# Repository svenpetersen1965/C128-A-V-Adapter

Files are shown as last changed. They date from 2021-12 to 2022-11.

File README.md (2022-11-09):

# C128-A-V-Adapter
An A/V-adaptor board for the Commodore C128. This board is intended to connect to the Commodore C128 and use standard cables (audio, composite with RCA connector and/or s-video with a mini-DIN cable).

It also provides a 330Ohm resistor, which attenuates the s-video chroma line. This resistor can be bridged with a jumper.

Also an optional stereo output on pin 7 of the a/v jack (stereo sid, FPGA SID etc.) can be connected to the right audio channel. By default, this channel is also connected to the (mono) audio output.

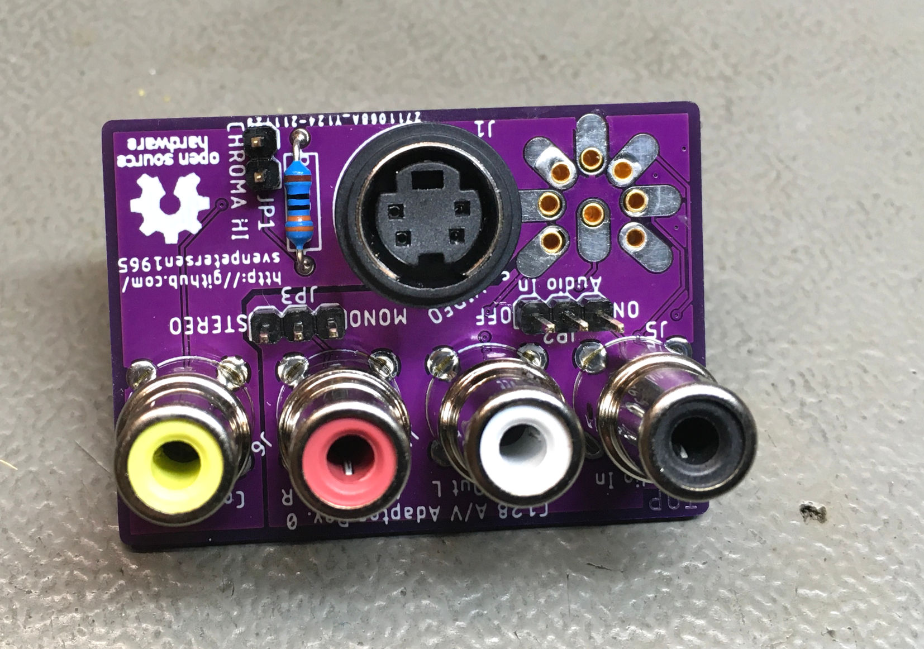
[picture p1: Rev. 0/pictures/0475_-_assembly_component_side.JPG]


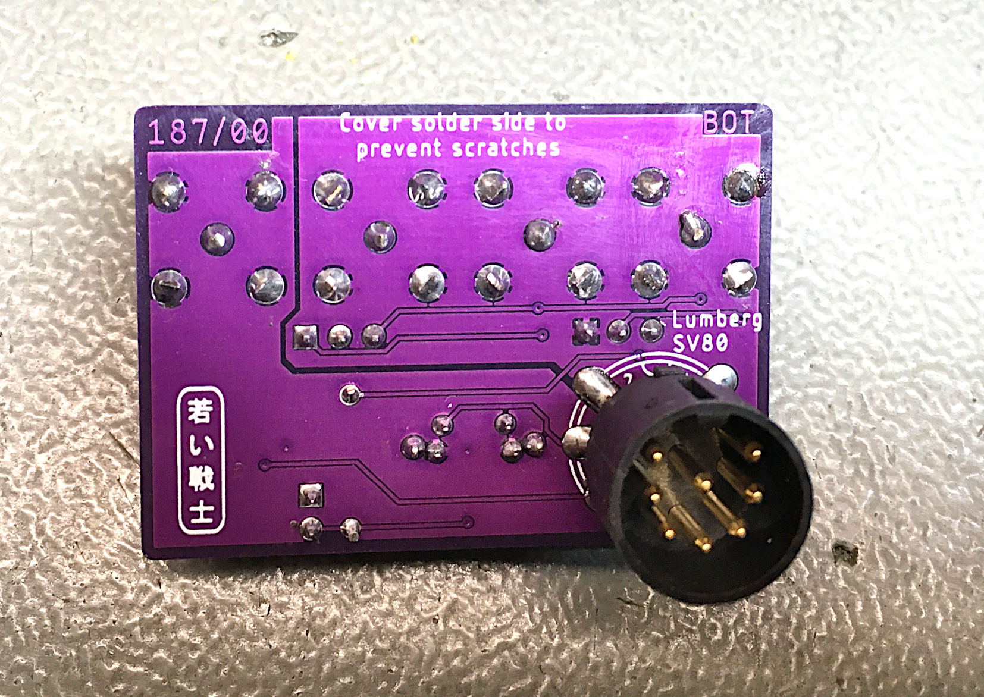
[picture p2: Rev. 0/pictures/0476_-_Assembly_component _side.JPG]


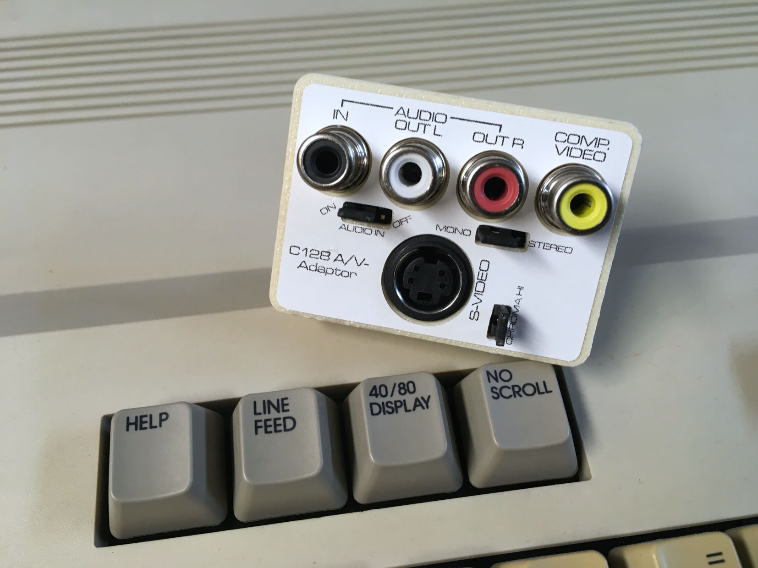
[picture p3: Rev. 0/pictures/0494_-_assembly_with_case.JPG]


# Rev. 1
This revision was required due to the obsolescence of the Lumberg BTOR1 RCA jacks. CUI Inc. RCJ-02* type conectors are used now. There are alternative RCA jacks from Keystone, which fit the same footprint (see BOM). Because of the new layout, a new case was required, too. There are recessions on the bottom shell for the solder pads, which have chancged in this board revision.

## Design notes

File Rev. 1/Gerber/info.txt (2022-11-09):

      
       Board: C128_AV-Adaptor
       Rev.:  1
  
       Files:
       ======
  
       All Gerber files are generated in extended gerber format (RS274X)
       *.TOP        : Film top copper
       *.BOT        :  -"- bottom copper
       *.STC        :  -"- top soldermask 
       *.STS        :  -"- bottom soldermask
       *.PLC        :  -"- silk screen top
       *.PLS        :  -"- silk screen bottom
       *.DK         : Drills plated Through (Excellon)
       *.NDK        : Drills not plated Through (Excellon)
       *.OUT        : Board outline

       Board Size:
       ===========
       Length     :   48.0 mm
       Width      :   34.0 mm
       Thickness  :   1.6 mm
       Material   :   FR 4
       Copper     :   35 um
       Surface    :   HASL
       
       Remarks:
       ========
       Width >= 8mil
       Distance >= 6mil
       Drill >= 0.6mm

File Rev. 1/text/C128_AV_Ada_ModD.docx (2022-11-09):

C128 A/V-Adaptor Rev. 1

Module Description

# Introduction

The A/V-Adaptor allows to connect standard S-Video and Audio or Composite-Video cables to the A/V-Jack of the Commodore C128.

A 330Ω resistor to attenuate the Chroma signal for S-Video is installed, but it can be deactivated by setting a jumper (JP2). This attenuation is required, since the chroma signal has a level, which is too high for standard S-Video. However, using the higher chroma signal can be desirable.

Further, the audio input can be connected to GND, in case it is not in use to reduce the noise introduction.

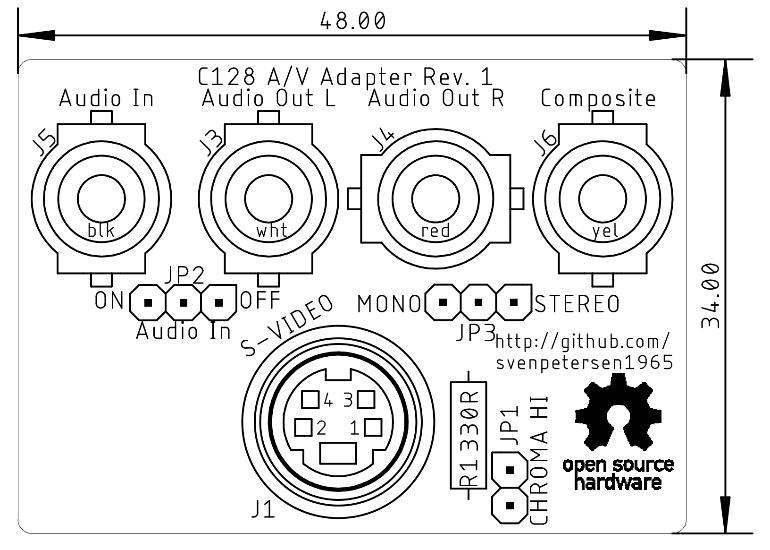
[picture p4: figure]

Figure 1: Component side of the A/V-Adaptor

The two audio output jacks can be connected by a jumper. Alternatively, the stereo sound output (A/V-Jack, pin 7, in case a 2nd SID is installed inside the C128) can be connected to the right channel of the audio output. The first SID output is connected to the left channel of the audio output.

# Connectors

## A/V-Plug – J2

The A/V-Plug for the C128 is the inner part of a Lumberg 033099 SV 80 DIN-Plug (8 pins, horse shoe = 262°). It provides a round plastic shell of the DIN-connector and long enough pins, so the adaptor can sit firmly in the A/V jack. The inner part of a cheaper (standard) connector cannot be used, since it does not sit firm enough.

Pin | Signal
1 | Luminance
2 | GND
3 | Audio Out (mono/left)
4 | Composite Video
5 | Audio In
6 | Chrominance
7 | Audio Out (right – if provided)
8 | -

## S-Video Jack – J1

A vertical PCB mount Mini-DIN jack (4 circuits)

Pin | Signal
1 | GND (Luminance)
2 | GND (Chrominance)
3 | Luminance
4 | Chrominance

## RCA-Jacks – J3, J4, J5 & J6

Connector | Signal
J3 | Audio Out (mono/left)
J4 | Audio Out (mono/right)
J5 | Audio In
J6 | Composite Video

# Jumpers

## Chrominance attenuation – JP1

The chrominance signal has a too high level for the standard S-Video chroma signal. The jumper bridges the 330Ω resistor (R1) to switch off this attenuation.

Status | Configuration
open | Attenuation active
Set | Attenuation inactive/off

## Audio Input Off – JP2

To reduce the noise introduction to the Audio Input, this can be grounded.

Status | Configuration
ON | SID Audio In connected to J5
OFF | SID Audio In connected to GND

## Mono/Stereo – JP3

The standard audio output of the SID is one channel (mono). In cases a 2nd SID is installed, the 2nd audio output is (usually) connected to Pin 7 of the Audio/Video jack of the C128. JP3 connected the right channel of the audio output (J4) to either J2, Pin 3 or Pin 7.

Status | Configuration
MONO | J4 connected to J2, Pin 3
STEREO | J4 connected to J2, Pin 7

# Assembly

Install the DIN plug (J2) on the solder side (bottom) first. Put the PCB on a suitable surface, the solder side up. Insert the DIN-plug, make sure, it is vertical and solder one pin first (from the solder side, which is pointing up, refer to Figure 2). Check again that the plug is straight, correct if required and finally solder all other pins.

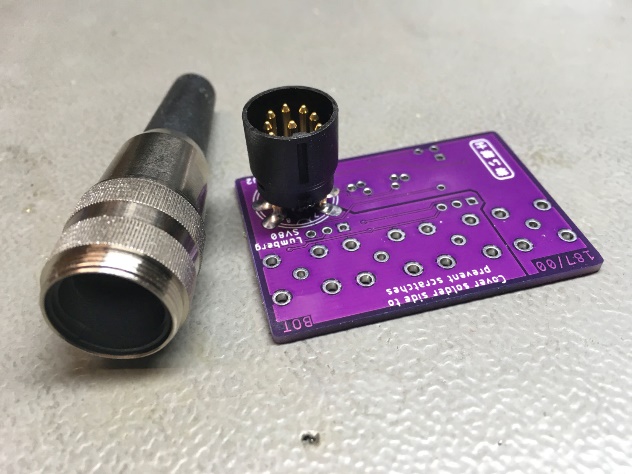
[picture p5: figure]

Figure 2: Soldering the DIN-plug J2 (PCB Rev. 0)

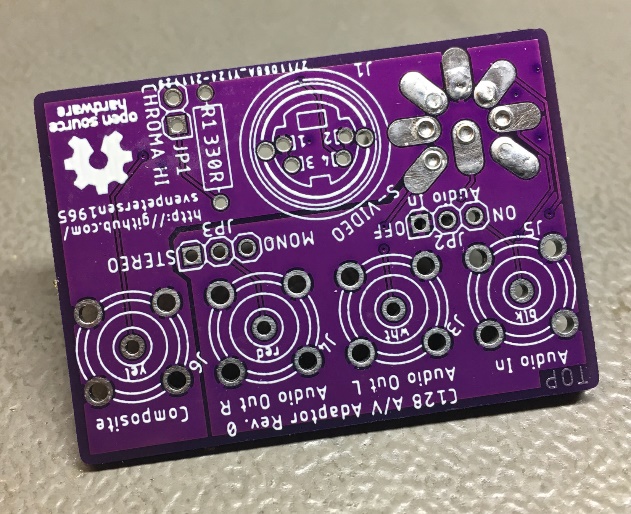
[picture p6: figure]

Figure 3: DIN-plug seen from the component side ("TOP") (PCB Rev. 0)

Install and solder all other components from the component side. Check the angle of the components, solder them from the solder side. Clip excess pin length.

In case no enclosure is used, cover the solder side (except J2) with duct tape to prevent scratching or install it in the provided 3D printed case.

# Revision History

## Rev. 0

- Fully functional prototype.

## Rev. 1

- The obsolete Lumberg BTOR1 RCA jacks were replaced by CUI Inc RCJ-02x type. There are alternative Keystone parts, that fit the same footprint (see BOM v1)
- A new 3D printed case is required.

C128_AV_Ada_ModD.docx 09.11.2022 10:47 Drafted by Sven Petersen Page 2 of 2 Doc.-No.: 187-6-01-01

C128_AV_Ada_ModD.docx 09.11.2022 10:47 Drafted by Sven Petersen Page 1 of 1 Doc.-No.: 000-6-00-00

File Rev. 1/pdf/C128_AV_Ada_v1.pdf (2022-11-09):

# Project Documentation

## C128 A/V-Adaptor

## Project number: 187

## Revision: 1

## Date: 28.08.2022

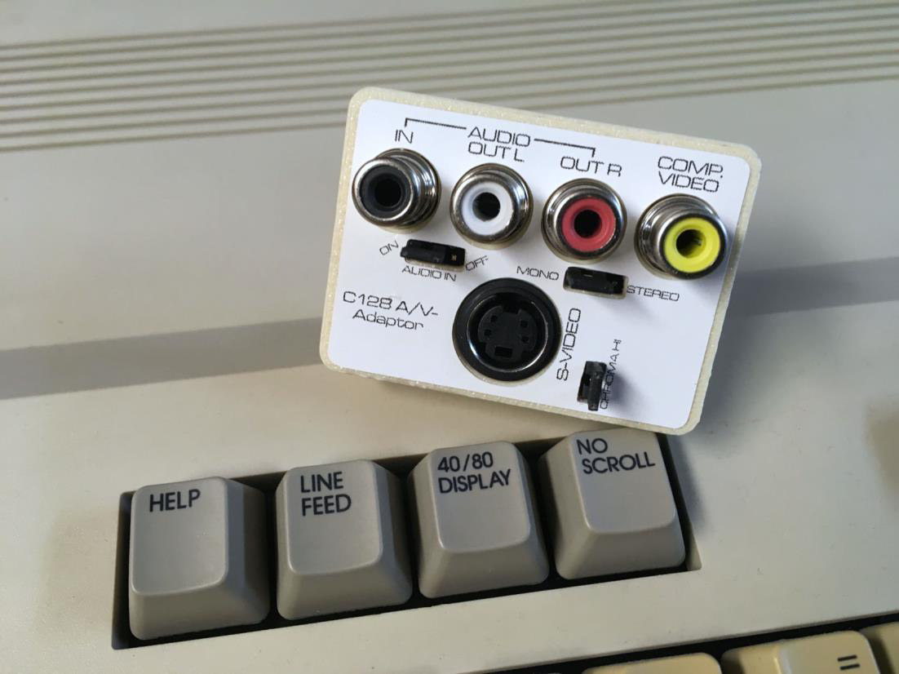
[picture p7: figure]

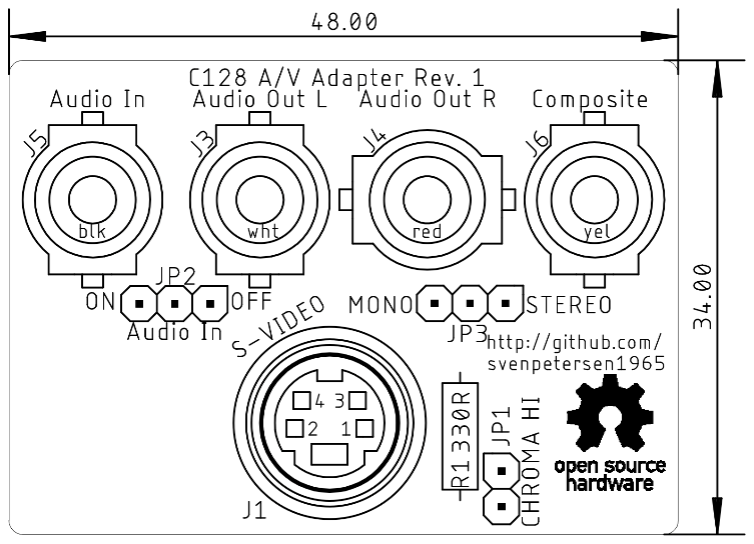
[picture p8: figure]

C128_AV_Ada_ModD.docx | | 09.11.2022 10:47
Drafted by Sven Petersen | Page 1 of 4 | Doc.-No.: 187-6-01-01

### C128 A/V-Adaptor Rev. 1

### Module Description

## Introduction

The A/V-Adaptor allows to connect standard S-Video and Audio or Composite-Video cables to the A/V-Jack of the Commodore C128.

A 330Ω resistor to attenuate the Chroma signal for S-Video is installed, but it can be deactivated by setting a jumper (JP2). This attenuation is required, since the chroma signal has a level, which is too high for standard S-Video. However, using the higher chroma signal can be desirable.

Further, the audio input can be connected to GND, in case it is not in use to reduce the noise introduction.

Figure 1: Component side of the A/V-Adaptor

The two audio output jacks can be connected by a jumper. Alternatively, the stereo sound output (A/V-Jack, pin 7, in case a 2nd SID is installed inside the C128) can be connected to the right channel of the audio output. The first SID output is connected to the left channel of the audio output.

## Connectors

### A/V-Plug – J2

The A/V-Plug for the C128 is the inner part of a Lumberg 033099 SV 80 DIN-Plug (8 pins, horse shoe = 262°). It provides a round plastic shell of the DIN-connector and long enough pins, so the adaptor can sit firmly in the A/V jack. The inner part of a cheaper (standard) connector cannot be used, since it does not sit firm enough.

C128_AV_Ada_ModD.docx | | 09.11.2022 10:47
Drafted by Sven Petersen | Page 2 of 4 | Doc.-No.: 187-6-01-01
Pin | Signal
1 Luminance
2 GND
3 Audio Out (mono/left)
4 Composite Video
5 Audio In
6 Chrominance
7 Audio Out (right – if provided) 8 -

### S-Video Jack – J1

A vertical PCB mount Mini-DIN jack (4 circuits)

Pin Signal
1 GND (Luminance)
2 GND (Chrominance)
3 Luminance
4 Chrominance

### RCA-Jacks – J3, J4, J5 & J6

Connector Signal
J3 | Audio Out (mono/left)
J4 | Audio Out (mono/right)
J5 | Audio In
J6 | Composite Video

## Jumpers

### Chrominance attenuation – JP1

The chrominance signal has a too high level for the standard S-Video chroma signal. The jumper bridges the 330Ω resistor (R1) to switch off this attenuation.

Status Configuration
open | Attenuation active
Set | Attenuation inactive/off

### Audio Input Off – JP2

To reduce the noise introduction to the Audio Input, this can be grounded.

Status Configuration
ON | SID Audio In connected to J5
OFF | SID Audio In connected to GND

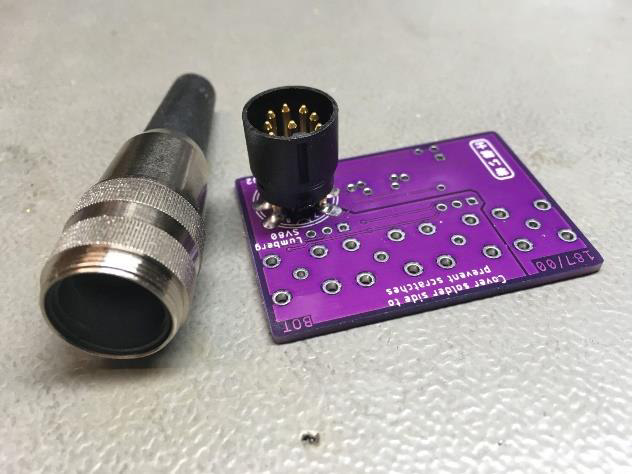
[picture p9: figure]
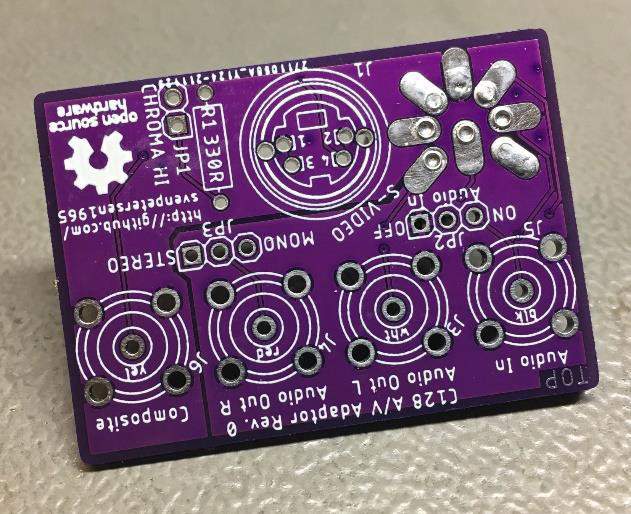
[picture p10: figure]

C128_AV_Ada_ModD.docx | | 09.11.2022 10:47
Drafted by Sven Petersen | Page 3 of 4 | Doc.-No.: 187-6-01-01

### Mono/Stereo – JP3

The standard audio output of the SID is one channel (mono). In cases a 2nd SID is installed, the 2nd audio output is (usually) connected to Pin 7 of the Audio/Video jack of the C128. JP3 connected the right channel of the audio output (J4) to either J2, Pin 3 or Pin 7.

Status | Configuration
MONO | J4 connected to J2, Pin 3
STEREO | J4 connected to J2, Pin 7

## Assembly

Install the DIN plug (J2) on the solder side (bottom) first. Put the PCB on a suitable surface, the solder side up. Insert the DIN-plug, make sure, it is vertical and solder one pin first (from the solder side, which is pointing up, refer to Figure 2). Check again that the plug is straight, correct if required and finally solder all other pins.

Figure 2: Soldering the DIN-plug J2 (PCB Rev. 0)

Figure 3: DIN-plug seen from the component side ("TOP") (PCB Rev. 0)

Install and solder all other components from the component side. Check the angle of the components, solder them from the solder side. Clip excess pin length.

In case no enclosure is used, cover the solder side (except J2) with duct tape to prevent scratching or install it in the provided 3D printed case.

C128_AV_Ada_ModD.docx | | 09.11.2022 10:47
Drafted by Sven Petersen | Page 4 of 4 | Doc.-No.: 187-6-01-01

## Revision History

### Rev. 0

- Fully functional prototype.

### Rev. 1

- The obsolete Lumberg BTOR1 RCA jacks were replaced by CUI Inc RCJ-02x type. There are alternative Keystone parts, that fit the same footprint (see BOM v1)
- A new 3D printed case is required.

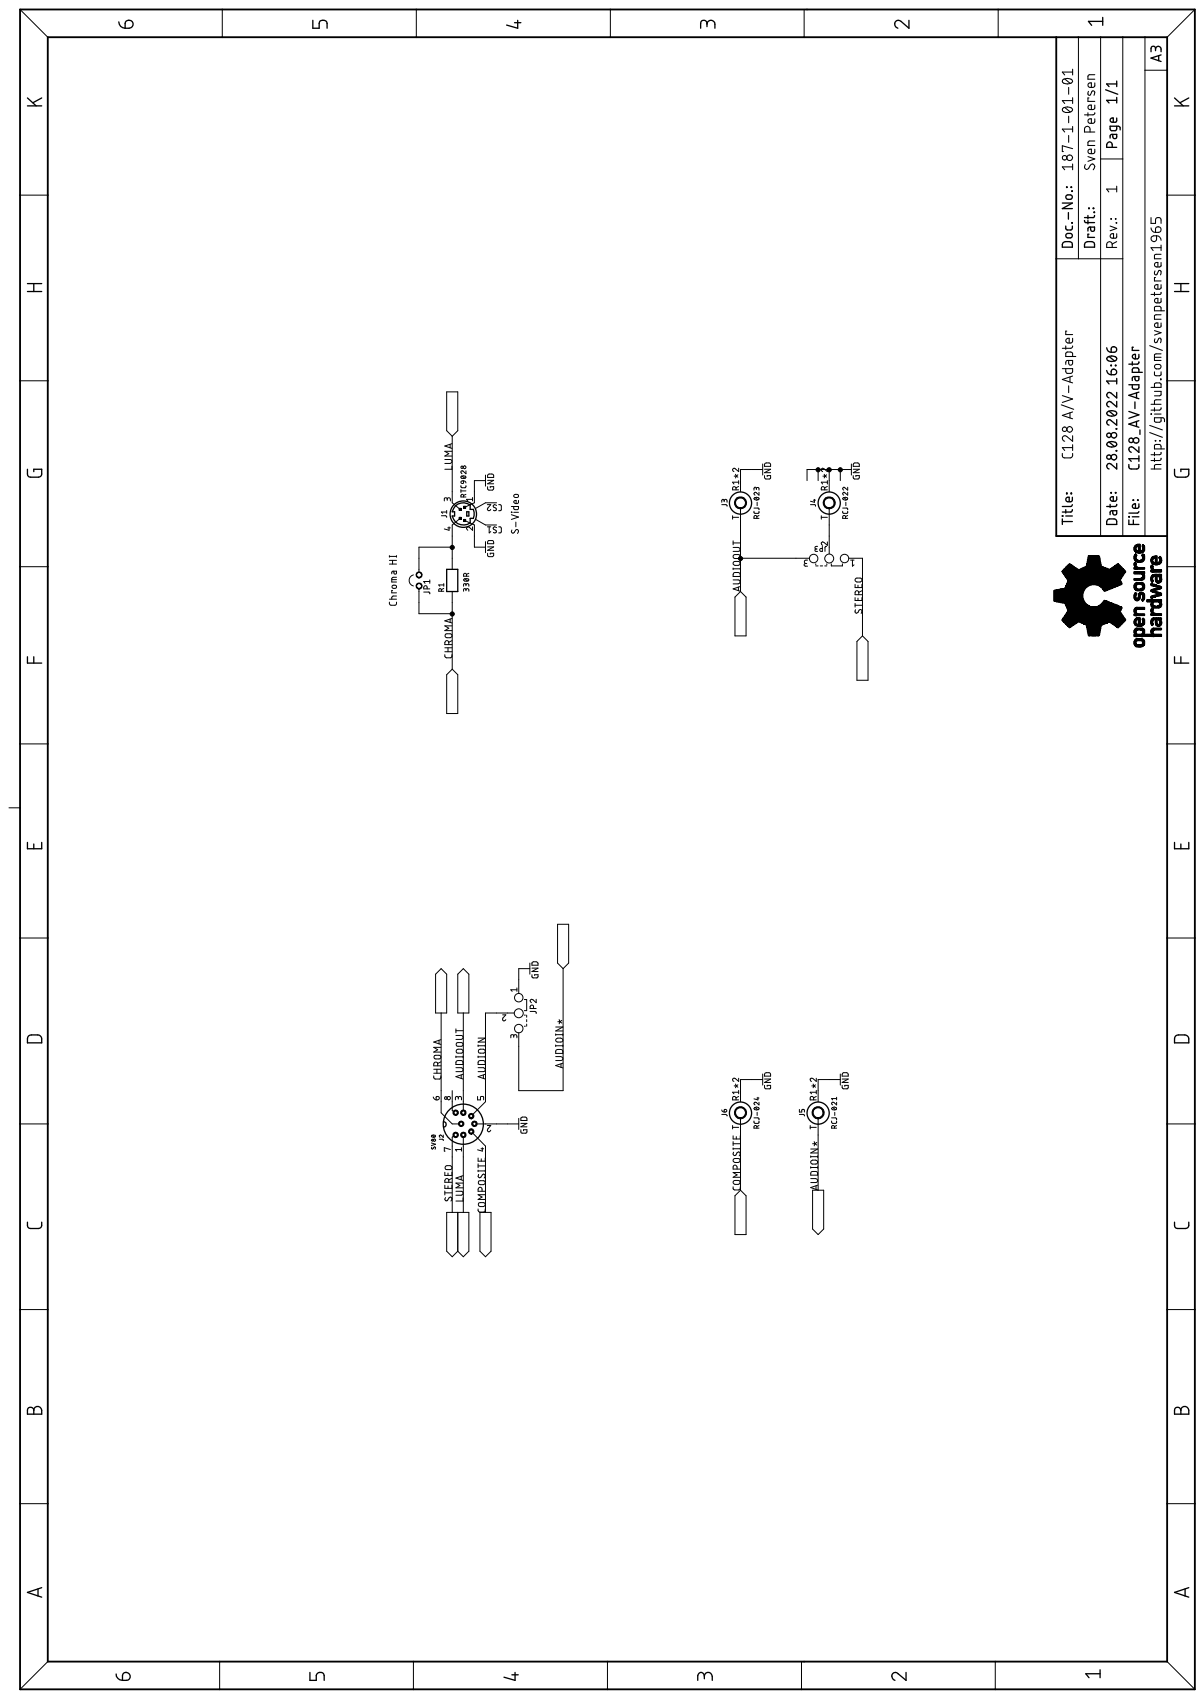
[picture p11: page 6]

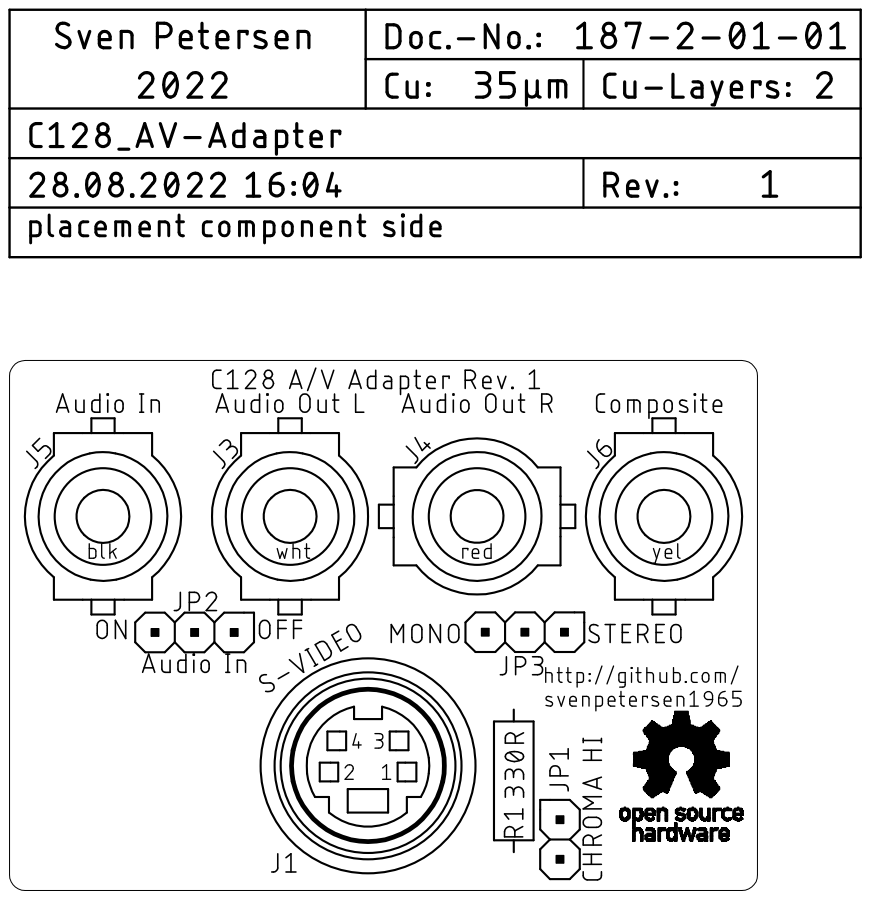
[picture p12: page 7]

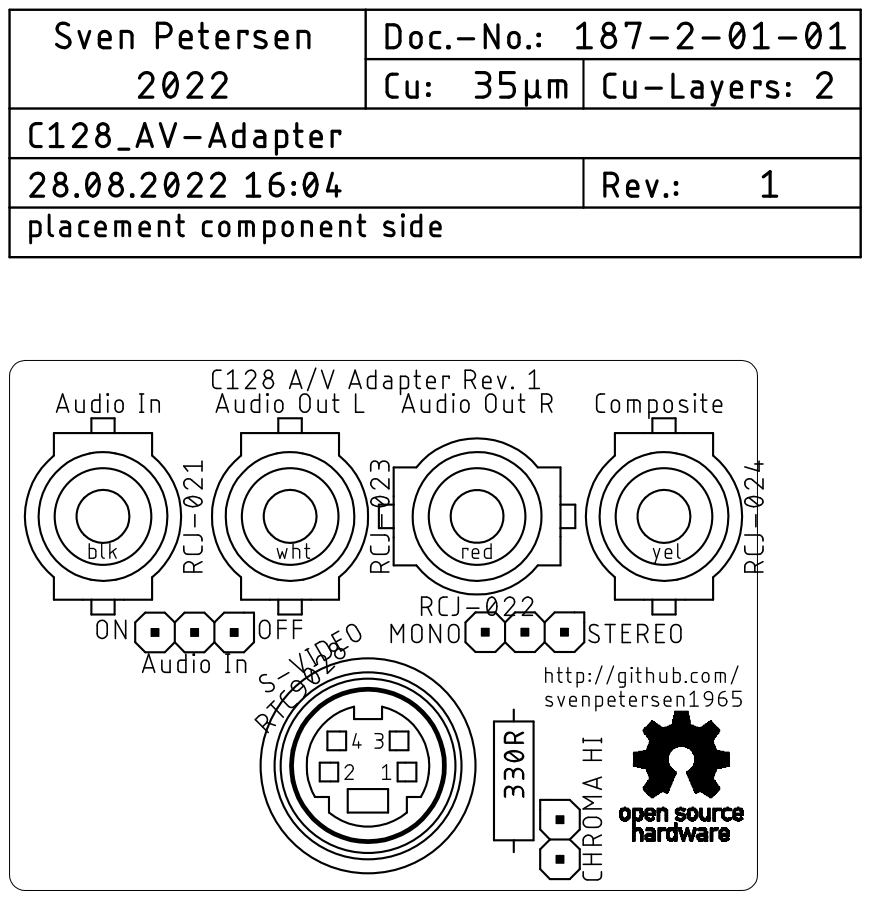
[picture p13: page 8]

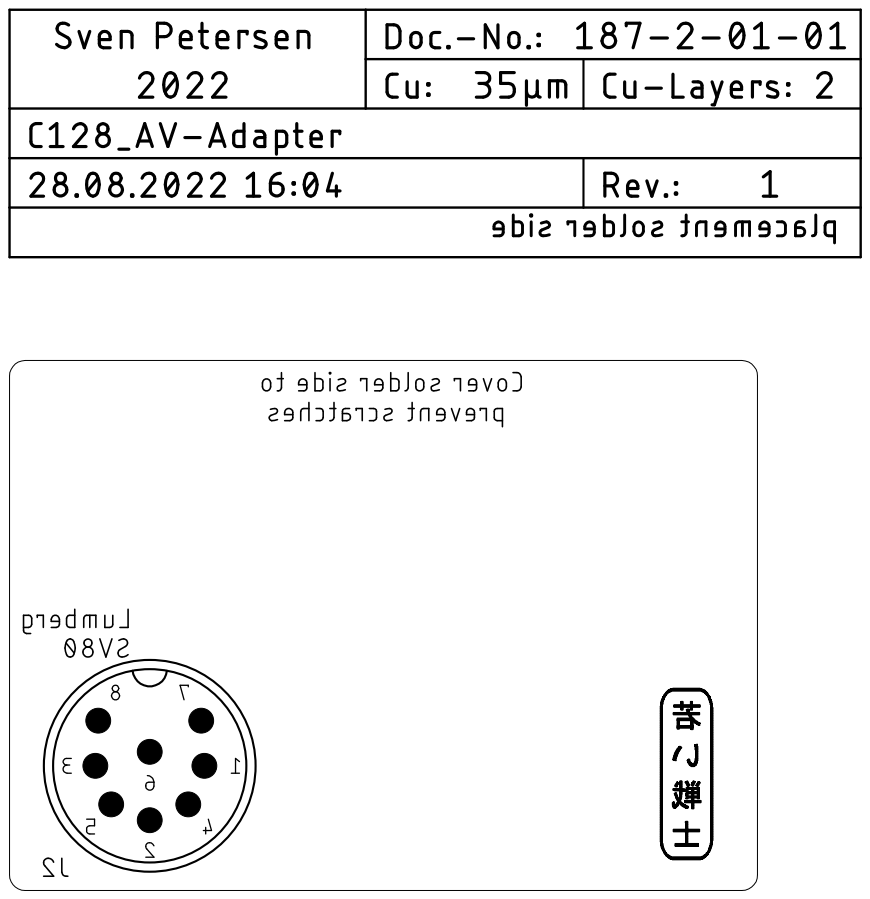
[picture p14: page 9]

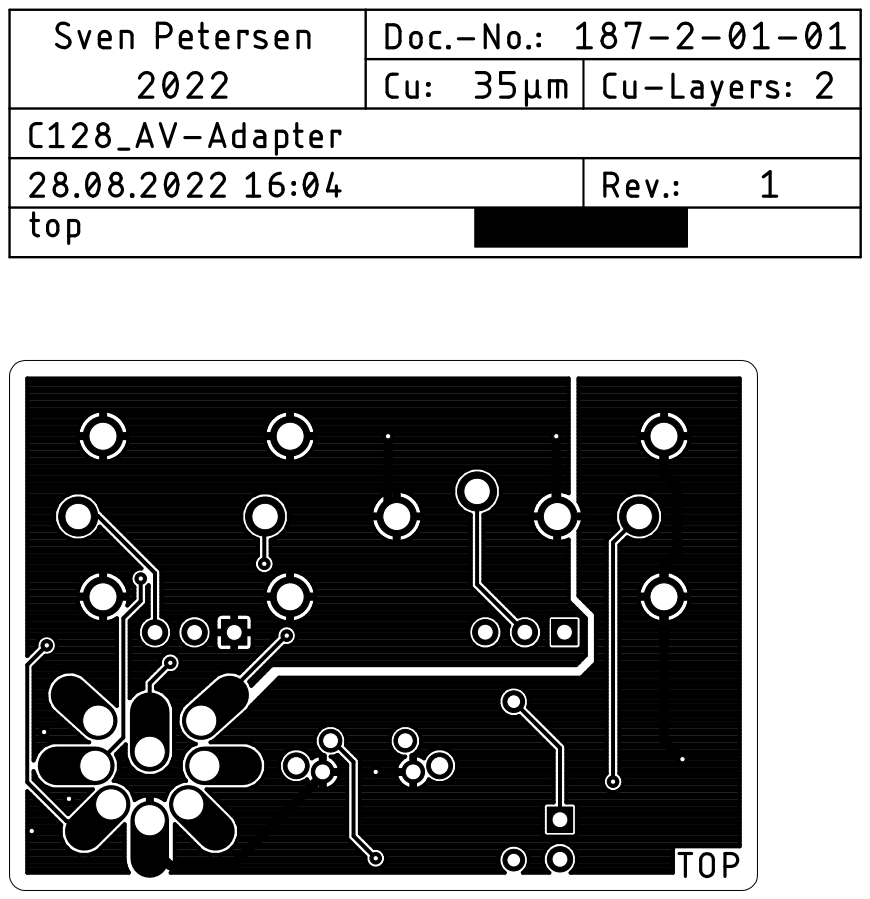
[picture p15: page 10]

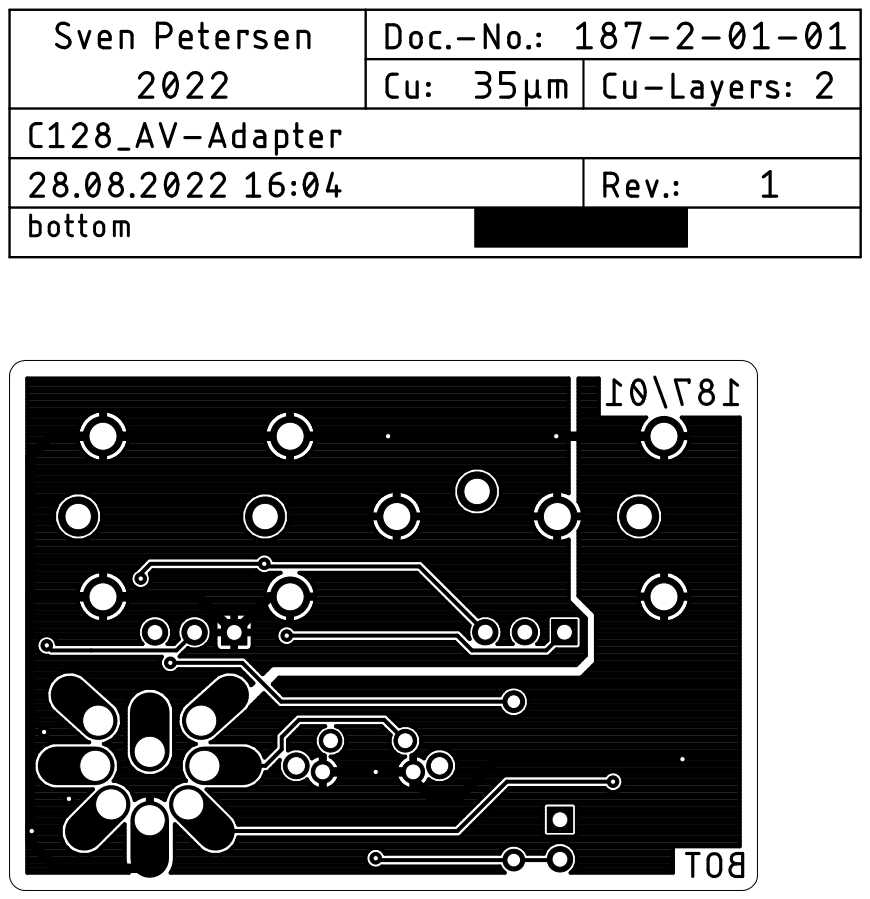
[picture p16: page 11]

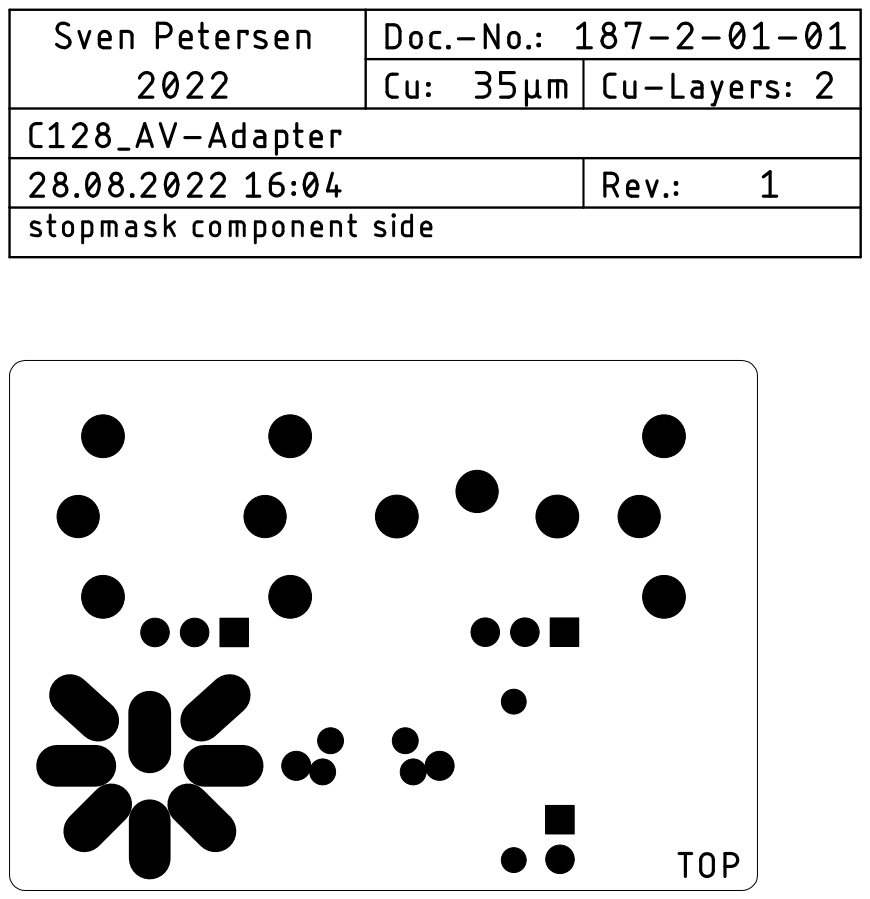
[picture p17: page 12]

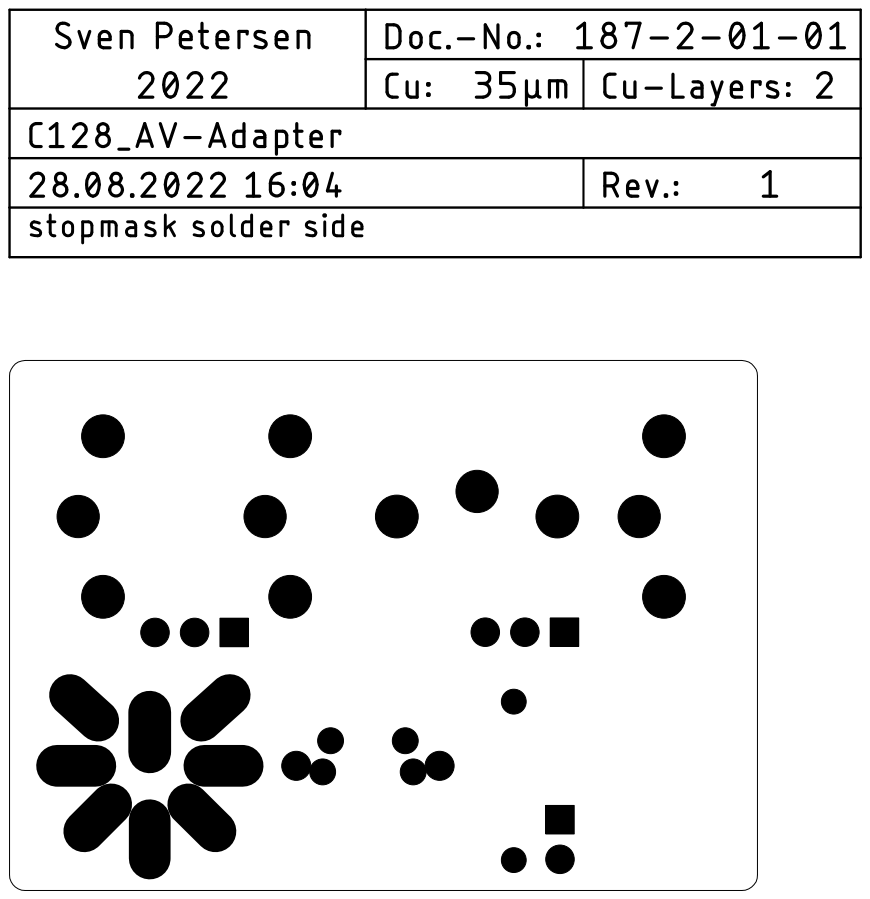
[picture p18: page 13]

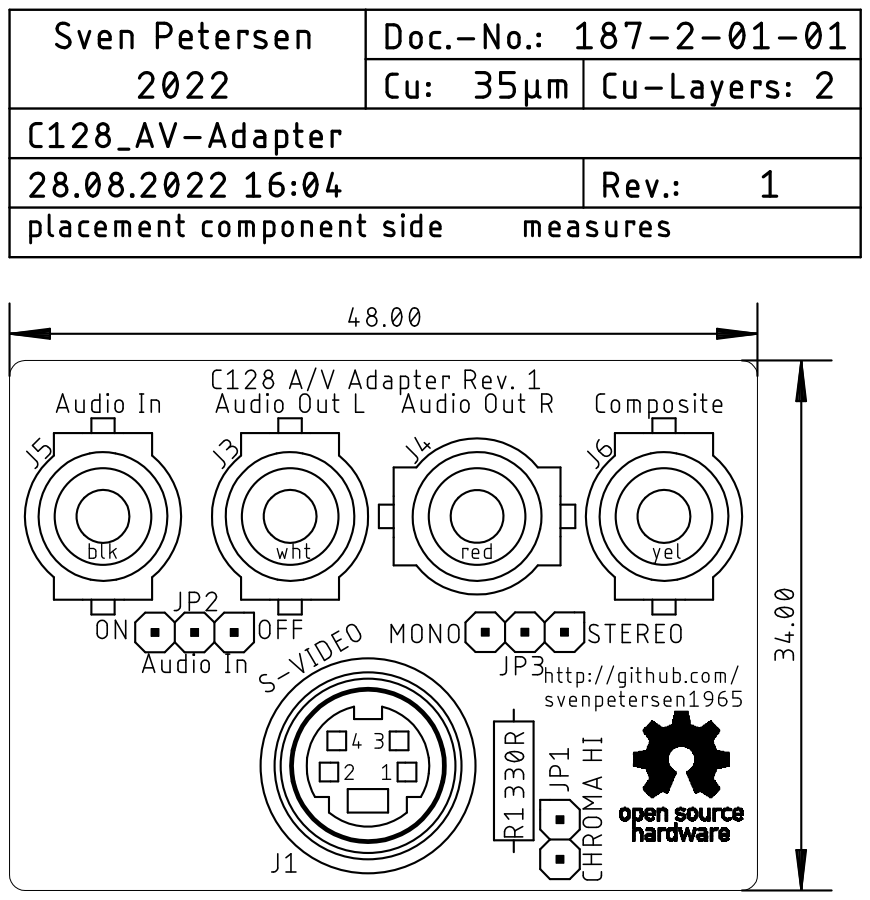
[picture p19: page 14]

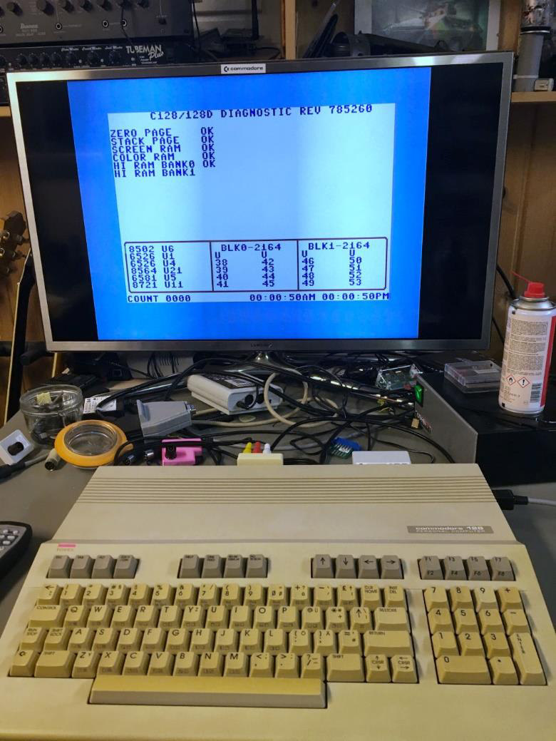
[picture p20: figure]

C128_AV_Ada_Test_1.docx | | 09.11.2022 17:33
Drafted by Sven Petersen | Page 1 of 4 | Doc.-No.: 187-6-02-01

### C128 A/V-Adaptor Rev. 1

### Testing v1.0

## Introduction

The test was conducted with a prototype of the A/V-Adaptor Rev. 1. For the electrical/functional tests a C128 was used. A Framemeister XRGB mini was used to connect an (HDMI) monitor.

Figure 1: Test Setup

## Tests

### Assembly

The prototype was assembled, all footprints worked out. The DIN plug was assembled the way described in the Module Description. No problems occurred while the assembly.

### Mechanical fitting

The A/V-Adaptor was installed on a C128, which works well with the prototype. It is required to install the DIN plug with a distance to the bottom side of the PCB to get deep enough into the video jack of the C128 to obtain a stabile seating.

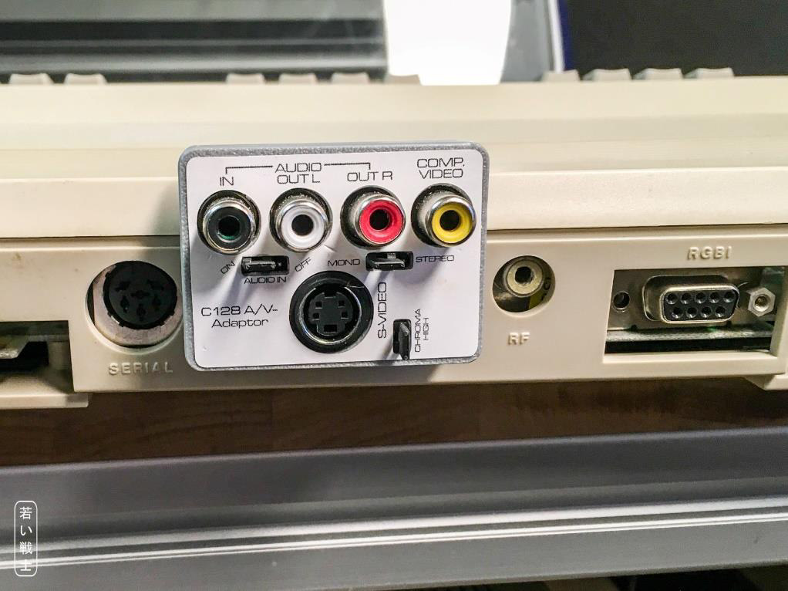
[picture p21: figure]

C128_AV_Ada_Test_1.docx | | 09.11.2022 17:33
Drafted by Sven Petersen | Page 2 of 4 | Doc.-No.: 187-6-02-01

Figure 2: Mechanical testing with a C128.

No ports are blocked.

### Functional testing

The A/V-adaptor was connected to the C128 and the computer was switched on. The jumpers were set to

Jumper | Setting
JP1 (Chroma Hi) | Close (=330R resistor bridged)
JP2 (Audio in) | Off (audio in → GND)
JP3 (mono/stereo) | Mono (both audio channels connected to J2, Pin 3)
Test | Result | Testing
S-Video cable connected | The displayed image was clear and not distorted | Ok
Audio cable | Both speakers had a clear audio output (mono) | Ok
Composite video | The displayed image was clear and not distorted | Ok
Audio input (JP2 → on) | The audio signal connected was passed through the filter. | Ok
Stereo mode | TBD | TBD
Chroma high (s-video), 330R resistor bridged | The quality of the displayed imaged changed. The colors got stronger and slightly distorted. This was expected. | Ok

The stereo mode was not tested.

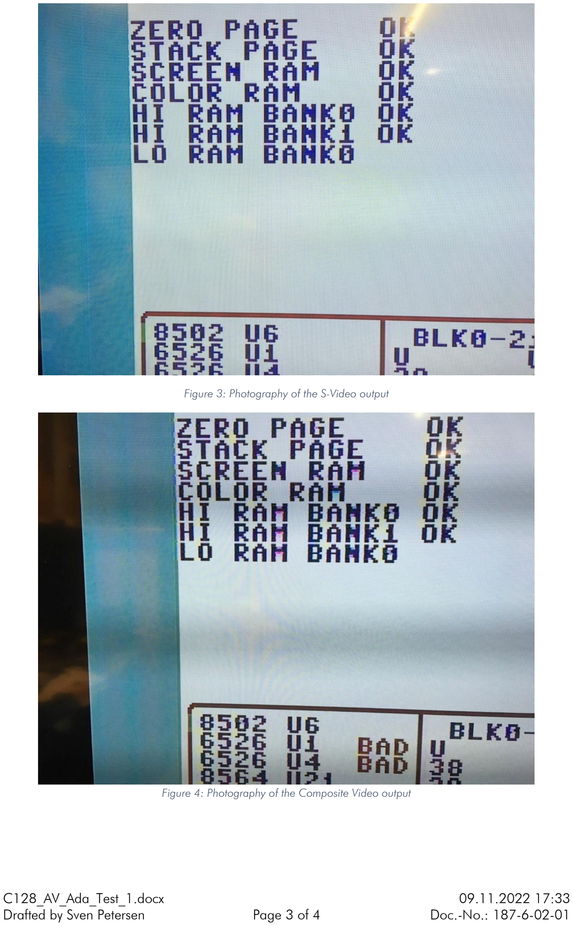
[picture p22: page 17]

C128_AV_Ada_Test_1.docx | | 09.11.2022 17:33
Drafted by Sven Petersen | Page 3 of 4 | Doc.-No.: 187-6-02-01

Figure 3: Photography of the S-Video output

Figure 4: Photography of the Composite Video output

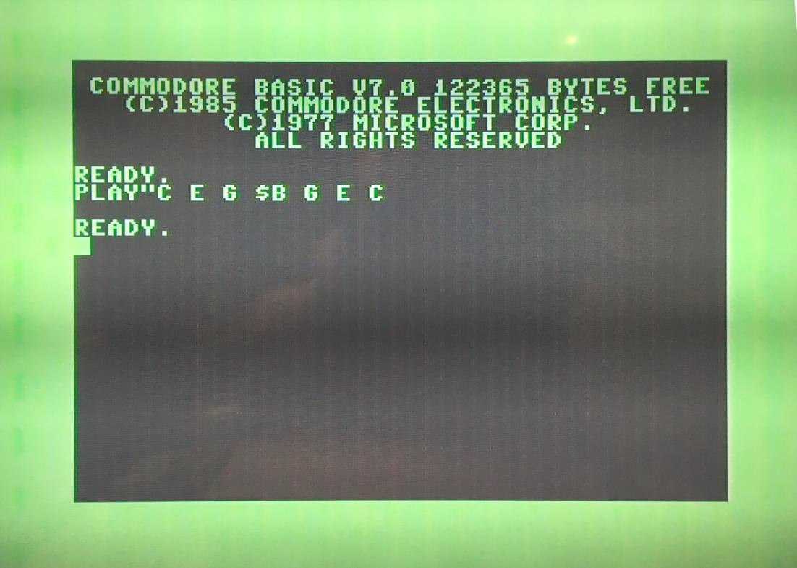
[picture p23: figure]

C128_AV_Ada_Test_1.docx | | 09.11.2022 17:33
Drafted by Sven Petersen | Page 4 of 4 | Doc.-No.: 187-6-02-01

Figure 5: Sound test

The sound test was accomplished by playing some notes from BASIC V7.0. These were audible.

NOTE: Photographing an TFT/LCD-Display never really shows the real image. That is matter due to raster effects (Moiré patterns) and dynamic effects (darker areas/strips).

### 3D-printed cases

After trimming the solder pins of the RCA jacks, all three versions of the board fit into the bottom shell. The respective top shells could be installed and fit well. The decals (labels) fit on the top shell.

The A/V-Adaptors passed a drop test (a drop of 1m on a table top).

## Test Result

The C128 A/V-Adaptor Rev. 1 is fully functional. It seems, that the colors of s-video and composite
video are looking more similar, when the jumper “Chroma High” is bridged.

Pos. Qty Value Footprint Ref.-No. Comment

1 1 187-2-01-01 2 Layer PCB Rev. 1 2 layer, Cu 35µ, HASL, 48.0mm x 34.0mm, 1.6mm FR4

2 2 1x 3p pin header, pitch

2.54mm

1X03 JP2, JP3 standard pin header, e.g. Reichelt RND 205-00624,

3 1 1x 2p pin header, pitch

2.54mm

1X02 JP1 standard pin header, e.g. Reichelt RND 205-00623

4 3 Jumper 2.54mm pitch jumper (JP1), (JP2), (JP3) Jumper (0,1") with holder/latch, e.g. tme.eu: JUMPER-H/B,
Farnell: 2396301, Newark: 93K5732 , Reichelt: JUMPER

2,54GL SW.

5 1 330R R-10 R1 resistor, 0.25W or more, 5% or better.

6 1 RCJ-021 RCJ-02X J5 CUI Inc., RCA jack, vertical, black. Mouser: 490-RCJ-021,
Digikey: CP-1406-ND. Alternative part: Keystone 585

7 1 RCJ-022 RCJ-02X J4 CUI Inc., RCA jack, vertical, red. Mouser: 490-RCJ-022,
Digikey: CP-1407-ND. Alternative part: Keystone 577

8 1 RCJ-023 RCJ-02X J3 CUI Inc., RCA jack, vertical, white. Mouser: 490-RCJ-023,
Digikey: CP-1408-ND. Alternative part: Keystone 584

9 1 RCJ-024 RCJ-02X J6 CUI Inc., RCA jack, vertical, yellow. Mouser: 490-RCJ-024,

Digikey: CP-1409-ND. Alternative part: Keystone 586

10 1 RTC9028 MINIDIN4_V J1 Mini-DIN, 4p, vertical. E.g. AliExpress:

RTConnector: RTC9028 (https://www.aliexpress.com/item/33032480787.html?spm=a2g0s.9042311.0.0.24354c4dZfdyek)

ebay.de (https://www.ebay.de/itm/5Stuck-Leiterplatten-Mount-4-Pin-Buchse-S-Jack-DVD-Mini-DIN-Sockel-Steckverbind/132869605733)

11 1 SV80 SV80_INNER J2 Inner part of Lumberg 033099 SV 80, e.G. Reichelt: LUM
SV 80, Newark: 23AH4043, Farnell: 1321482, TME.eu:
SV80, alliedelec.com: 70151558. LUM SV 50 for 5-pin

C64 and VIC-20

## C128 A/V-Adaptor Rev. 1

## Bill of Material Rev. 1.0

C128_AV_Adapt_BOM_v1_0.xlsx

Drafted by Sven Petersen Page 1 of 1

09.11.2022 17:36
Doc.No.: 187-5-01-01.0

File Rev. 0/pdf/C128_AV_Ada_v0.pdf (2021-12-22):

# Project Documentation

## C128 A/V-Adaptor

## Project number: 187

## Revision: 0

## Date: 22.12.2021


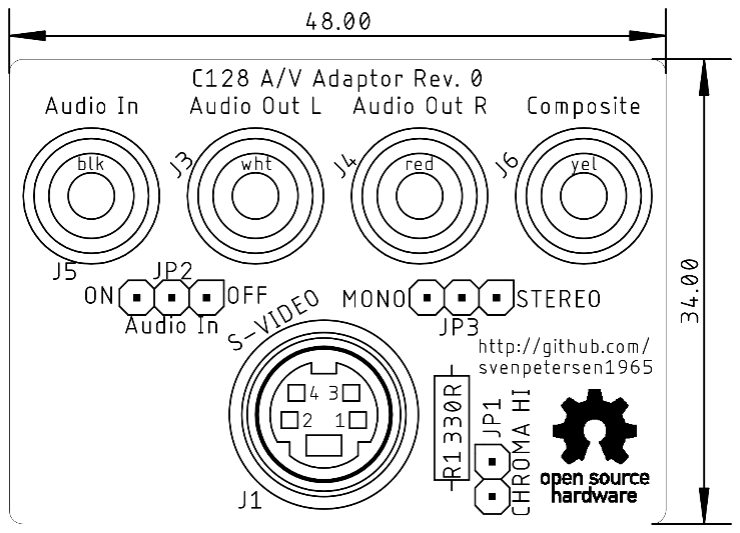
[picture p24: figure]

C128_AV_Ada_ModD.docx | | 22.12.2021 15:43
Drafted by Sven Petersen | Page 1 of 4 | Doc.-No.: 187-6-01-00

### C128 A/V-Adaptor Rev. 0

### Module Description

## Introduction

The A/V-Adaptor allows to connect standard S-Video and Audio or Composite-Video cables to the A/V-Jack of the Commodore C128.

A 330Ω resistor to attenuate the Chroma signal for S-Video is installed, but it can be deactivated by setting a jumper (JP2). This attenuation is required, since the chroma signal has a level, which is too high for standard S-Video. However, using the higher chroma signal can be desirable.

Further, the audio input can be connected to GND, in case it is not in use to reduce the noise introduction.

Figure 1: Component side of the A/V-Adaptor

The two audio output jacks can be connected by a jumper. Alternatively, the stereo sound output (A/V-Jack, pin 7, in case a 2nd SID is installed inside the C128) can be connected to the right channel of the audio output. The first SID output is connected to the left channel of the audio output.

## Connectors

### A/V-Plug – J2

The A/V-Plug for the C128 is the inner part of a Lumberg 033099 SV 80 DIN-Plug (8 pins, horse shoe = 262°). It provides a round plastic shell of the DIN-connector and long enough pins, so the adaptor can sit firmly in the A/V jack. The inner part of a cheaper (standard) connector cannot be used, since it does not sit firm enough.

C128_AV_Ada_ModD.docx | | 22.12.2021 15:43
Drafted by Sven Petersen | Page 2 of 4 | Doc.-No.: 187-6-01-00
Pin | Signal
1 Luminance
2 GND
3 Audio Out (mono/left)
4 Composite Video
5 Audio In
6 Chrominance
7 Audio Out (right – if provided) 8 -

### S-Video Jack – J1

A vertical PCB mount Mini-DIN jack (4 circuits)

Pin Signal
1 GND (Luminance)
2 GND (Chrominance)
3 Luminance
4 Chrominance

### RCA-Jacks – J3, J4, J5 & J6

Connector Signal
J3 | Audio Out (mono/left)
J4 | Audio Out (mono/right)
J5 | Audio In
J6 | Composite Video

## Jumpers

### Chrominance attenuation – JP1

The chrominance signal has a too high level for the standard S-Video chroma signal. The jumper bridges the 330Ω resistor (R1) to switch off this attenuation.

Status Configuration
open | Attenuation active
Set | Attenuation inactive/off

### Audio Input Off – JP2

To reduce the noise introduction to the Audio Input, this can be grounded.

Status Configuration
ON | SID Audio In connected to J5
OFF | SID Audio In connected to GND


C128_AV_Ada_ModD.docx | | 22.12.2021 15:43
Drafted by Sven Petersen | Page 3 of 4 | Doc.-No.: 187-6-01-00

### Mono/Stereo – JP3

The standard audio output of the SID is one channel (mono). In cases a 2nd SID is installed, the 2nd audio output is (usually) connected to Pin 7 of the Audio/Video jack of the C128. JP3 connected the right channel of the audio output (J4) to either J2, Pin 3 or Pin 7.

Status | Configuration
MONO | J4 connected to J2, Pin 3
STEREO | J4 connected to J2, Pin 7

## Assembly

Install the DIN plug (J2) on the solder side (bottom) first. Put the PCB on a suitable surface, the solder side up. Insert the DIN-plug, make sure, it is vertical and solder one pin first (from the solder side, which is pointing up, refer to Figure 2). Check again that the plug is straight, correct if required and finally solder all other pins.

Figure 2: Soldering the DIN-plug J2

Figure 3: DIN-plug seen from the component side ("TOP")

Install and solder all other components from the component side. Watch the angle of the components, solder them from the solder side. Clip excess pin length.

In case no enclosure is used, cover the solder side (except J2) with duct tape to prevent scratching or install it in the provided 3D printed case.

C128_AV_Ada_ModD.docx | | 22.12.2021 15:43
Drafted by Sven Petersen | Page 4 of 4 | Doc.-No.: 187-6-01-00

## Revision History

### Rev. 0

Fully functional prototype.

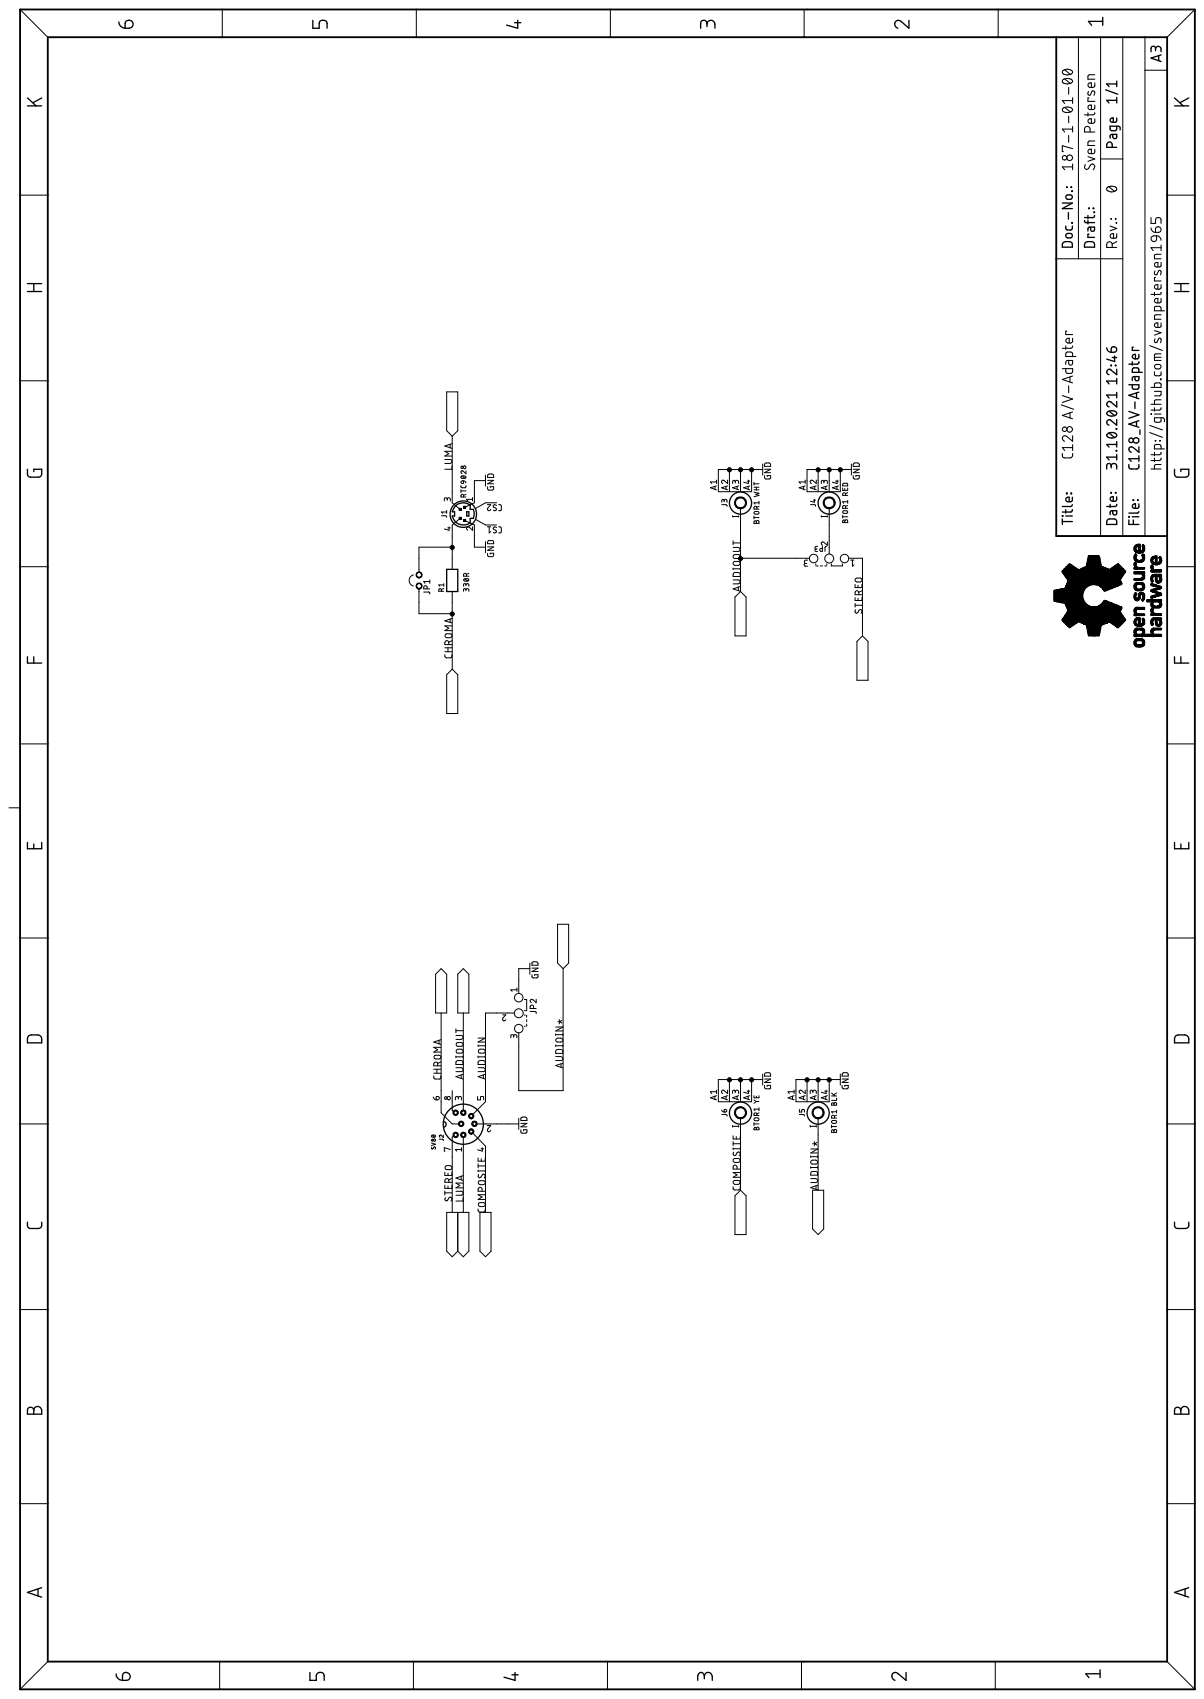
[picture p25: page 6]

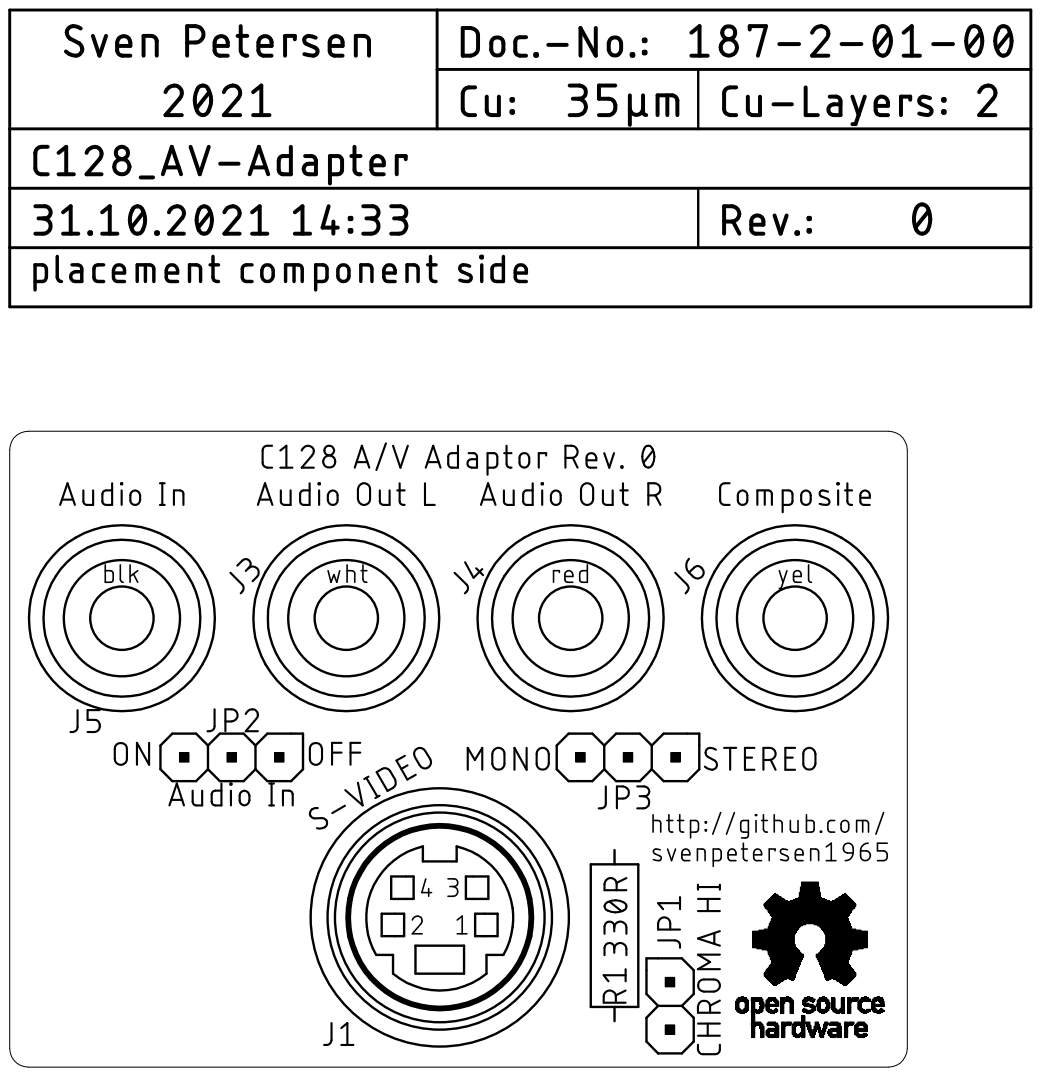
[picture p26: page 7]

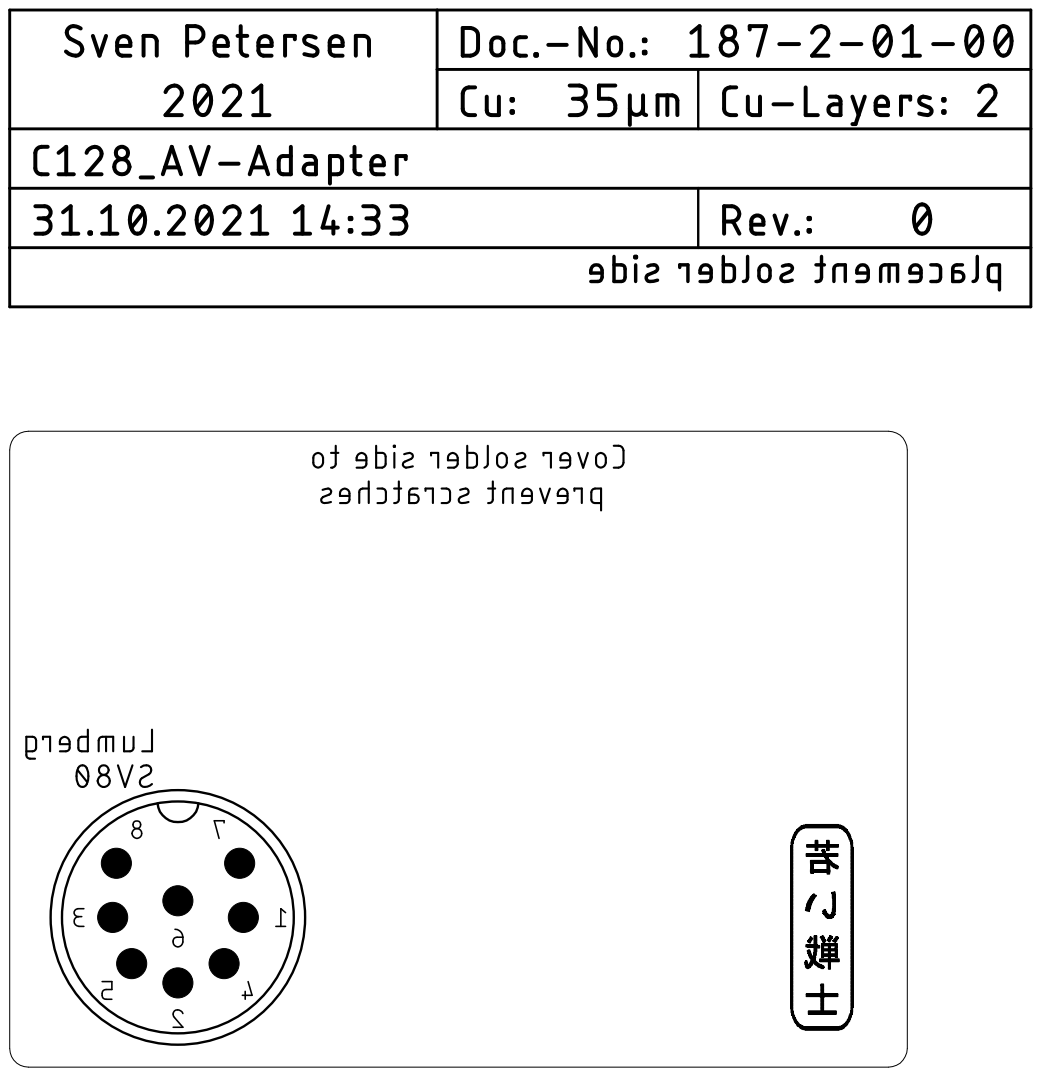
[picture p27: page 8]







C128_AV_Ada_Test_0.docx | | 22.12.2021 18:18
Drafted by Sven Petersen | Page 1 of 4 | Doc.-No.: 132-6-02-01

### C128 A/V-Adaptor Rev. 0

### Testing v0.0

## Introduction

The test was conducted with a prototype of the A/V-Adaptor Rev. 0. For the electrical/functional tests a C128 was used. A Framemeister XRGB mini was used to connect an (HDMI) monitor.

Figure 1: Test Setup

## Tests

### Assembly

The prototype was assembled, all footprints worked out. The DIN plug was assembled the way described in the Module Description. No problems occurred while the assembly.

### Mechanical fitting

The A/V-Adaptor was installed on a C128, which works well with the prototype. It is required to install the DIN plug with a distance to the bottom side of the PCB to get deep enough into the video jack of the C128 to obtain a stabile seating.


C128_AV_Ada_Test_0.docx | | 22.12.2021 18:18
Drafted by Sven Petersen | Page 2 of 4 | Doc.-No.: 132-6-02-01

Figure 2: Mechanical testing with a C128.

No ports are blocked.

### Functional testing

The A/V-adaptor was connected to the C128 and the computer was switched on. The jumpers were set to

Jumper | Setting
JP1 (Chroma Hi) | Close (=330R resistor bridged)
JP2 (Audio in) | Off (audio in → GND)
JP3 (mono/stereo) | Mono (both audio channels connected to J2, Pin 3)
Test | Result | Testing
S-Video cable connected | The displayed image was clear and not distorted | Ok
Audio cable | Both speakers had a clear audio output (mono) | Ok
Composite video | The displayed image was clear and not distorted | Ok
Audio input (JP2 → on) | The audio signal connected was passed through the filter. | Ok
Stereo mode | TBD | TBD
Chroma high (s-video), 330R resistor bridged | The quality of the displayed imaged changed. The colors got stronger and slightly distorted. This was expected. | Ok

The stereo mode was not tested.


C128_AV_Ada_Test_0.docx | | 22.12.2021 18:18
Drafted by Sven Petersen | Page 3 of 4 | Doc.-No.: 132-6-02-01

Figure 3: Photography of the S-Video output

Figure 4: Photography of the Composite Video output


C128_AV_Ada_Test_0.docx | | 22.12.2021 18:18
Drafted by Sven Petersen | Page 4 of 4 | Doc.-No.: 132-6-02-01

Figure 5: Sound test

The sound test was accomplished by playing some notes from BASIC V7.0. These were audible.

NOTE: Photographing an TFT/LCD-Display never really shows the real image. That is matter due to raster effects (Moiré patterns) and dynamic effects (darker areas/strips).

### 3D-printed cases

After trimming the solder pins of the RCA jacks, all three versions of the board fit into the bottom shell. The respective top shells could be installed and fit well. The decals (labels) fit on the top shell.

The A/V-Adaptors passed a drop test (a drop of 1m on a table top).

## Test Result

The C128 A/V-Adaptor Rev. 0 is fully functional. It seems, that the colors of s-video and composite video are looking more similar, when the jumper “Chroma High” is bridged.

Pos. Qty Value Footprint Ref.-No. Comment

1 1 187-2-01-00 2 Layer PCB Rev. 0 2 layer, Cu 35µ, HASL, 48.0mm x 34.0mm, 1.6mm FR4

2 2 1x 3p pin header, pitch

2.54mm

1X03 JP2, JP3 standard pin header, e.g. Reichelt RND 205-00624,

3 1 1x 2p pin header, pitch

2.54mm

1X02 JP1 standard pin header, e.g. Reichelt RND 205-00623

4 3 Jumper 2.54mm pitch jumper (JP1), (JP2), (JP3) Jumper (0,1") with holder/latch, e.g. tme.eu: JUMPER-H/B,
Farnell: 2396301, Newark: 93K5732 , Reichelt: JUMPER

2,54GL SW.

5 1 330R R-10 R1 resistor, 0.25W or more, 5% or better.

6 1 BTOR1 (black) BTOR1 J5 Lumberg, RCA jack, vertical, black. E.G. Reichelt LUM
BTOR1 SW, Farnell: 1217030, Newark: 96K7172,

TME.eu: BTOR1B

7 1 BTOR1 RED BTOR1 J4 Lumberg, RCA jack, vertical, red. E.G. Reichelt LUM BTOR1

RT, Farnell: 1368644, Newark: 53M6863, TME.eu:

BTOR1R

8 1 BTOR1 WHITE BTOR1 J3 Lumberg, RCA jack, vertical, white. E.G. Reichelt LUM
BTOR1 WS, Farnell: 1368645, Newark: 53M6864,

TME.eu: BTOR1W

9 1 BTOR1 YELLOW BTOR1 J6 Lumberg, RCA jack, vertical, yellow. E.G. Reichelt LUM
BTOR1 GE, Farnell: 1368642, Newark: 53M6865,

TME.eu: BTOR1Y

10 1 RTC9028 MINIDIN4_V J1 Mini-DIN, 4p, vertical. E.g. AliExpress:

RTConnector: RTC9028 (https://www.aliexpress.com/item/33032480787.html?spm=a2g0s.9042311.0.0.24354c4dZfdyek)

ebay.de (https://www.ebay.de/itm/5Stuck-Leiterplatten-Mount-4-Pin-Buchse-S-Jack-DVD-Mini-DIN-Sockel-Steckverbind/132869605733)

11 1 SV80 SV80_INNER J2 Inner part of Lumberg 033099 SV 80, e.G. Reichelt: LUM
SV 80, Newark: 23AH4043, Farnell: 1321482, TME.eu:
SV80, alliedelec.com: 70151558. LUM SV 50 for 5-pin

C64 and VIC-20

## C128 A/V-Adaptor Rev. 0

## Bill of Material Rev. 0.0

C128_AV_Adapt_BOM_v0_0.xlsx

Drafted by Sven Petersen Page 1 of 2

22.12.2021 18:18
Doc.No.: 187-5-01-00.0

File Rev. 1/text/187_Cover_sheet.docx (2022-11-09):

Project Documentation

C128 A/V-Adaptor

Project number: 187

Revision: 1

Date: 28.08.2022


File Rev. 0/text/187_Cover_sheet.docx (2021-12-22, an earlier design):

Project Documentation

C128 A/V-Adaptor

Project number: 187

Revision: 0

Date: 22.12.2021


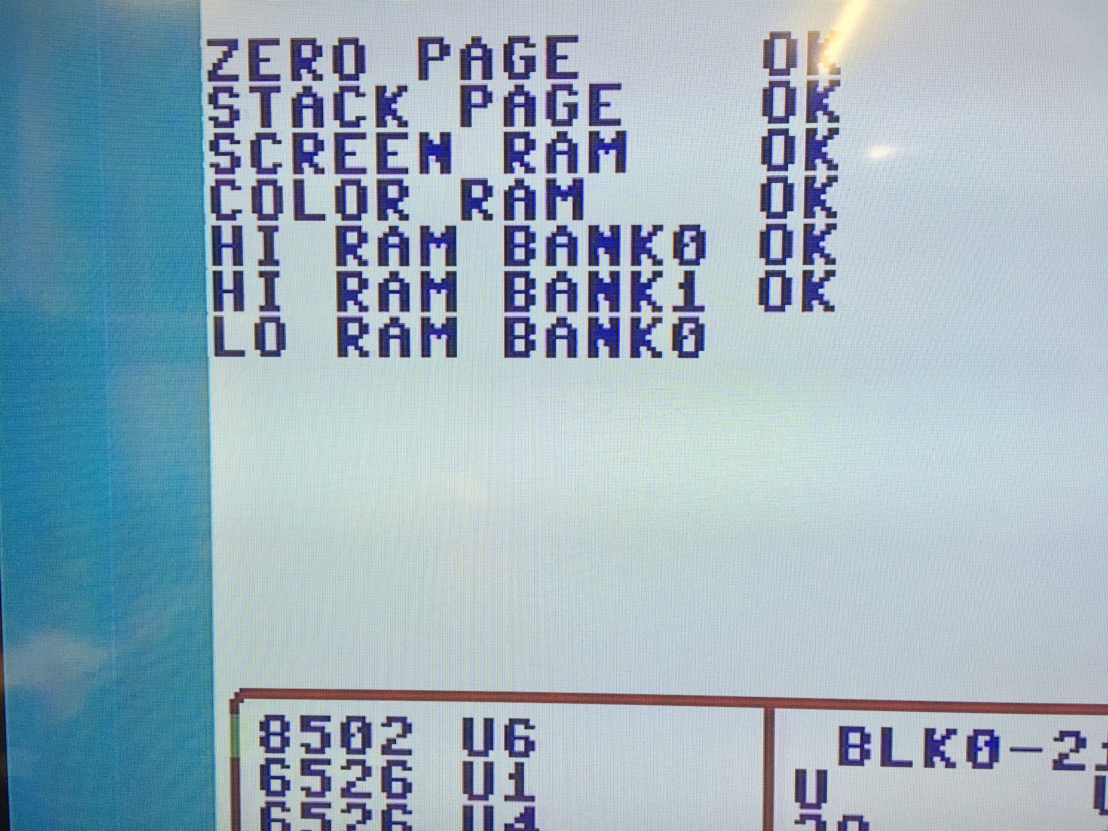
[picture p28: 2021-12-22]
Rev. 1/pictures/0481_-_s-video.JPG

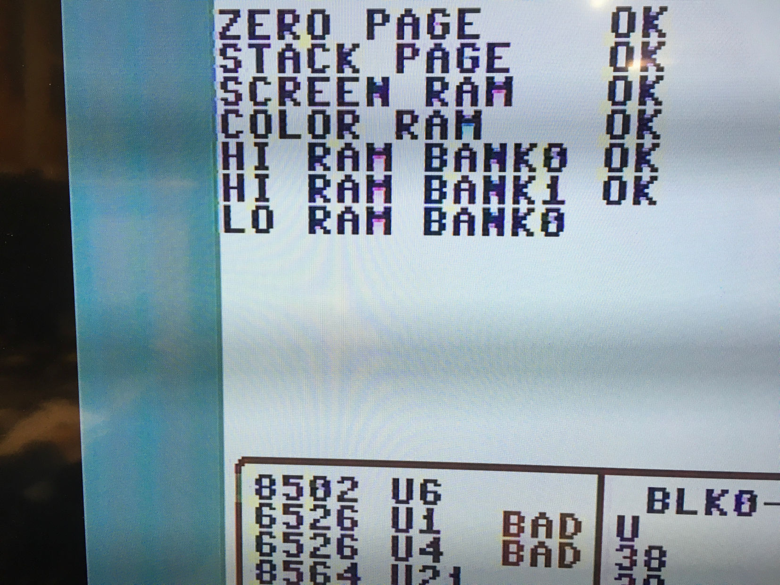
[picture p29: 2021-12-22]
Rev. 1/pictures/0482_-_composite.JPG

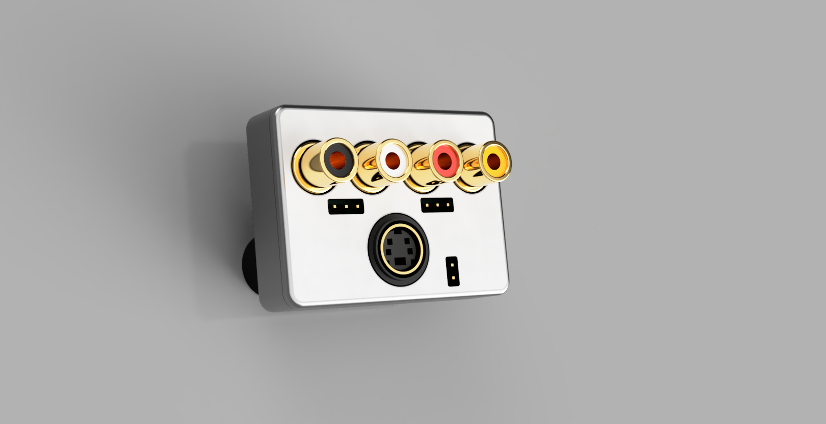
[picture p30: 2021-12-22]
Rev. 1/pictures/Rendered_image.PNG

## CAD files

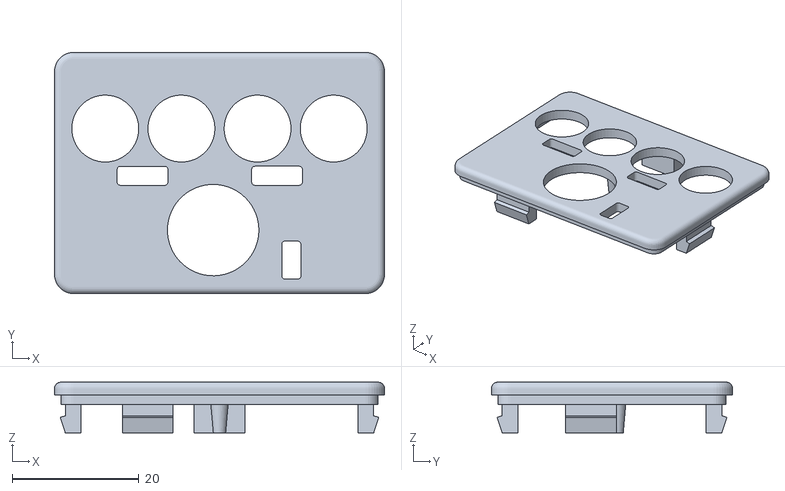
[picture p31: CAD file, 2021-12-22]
3D-printed case/Rev. 0/stl/C128_AVada_top.stl
52.0 x 38.0 x 8.00

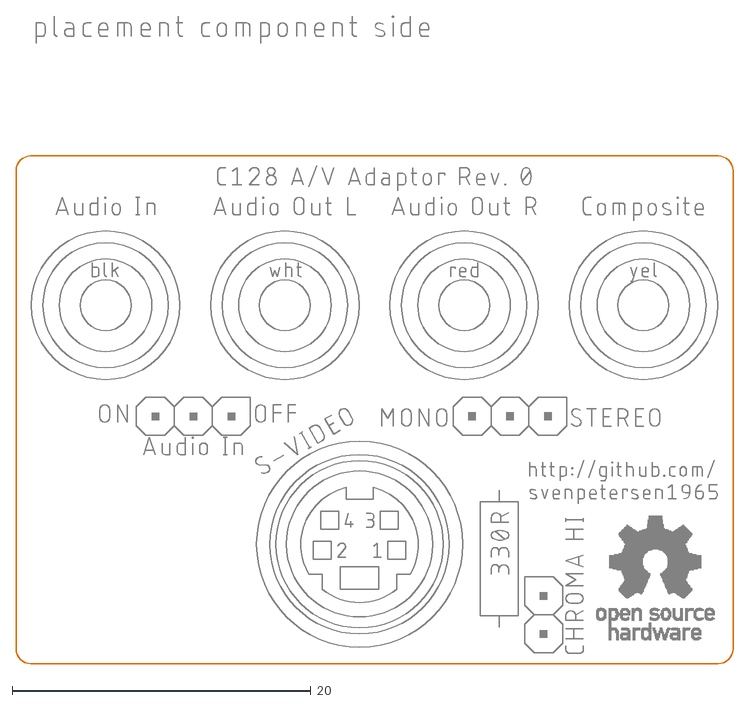
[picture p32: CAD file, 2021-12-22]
Rev. 0/dxf/C128_AV-Adapter_top.dxf
48.0 x 43.3

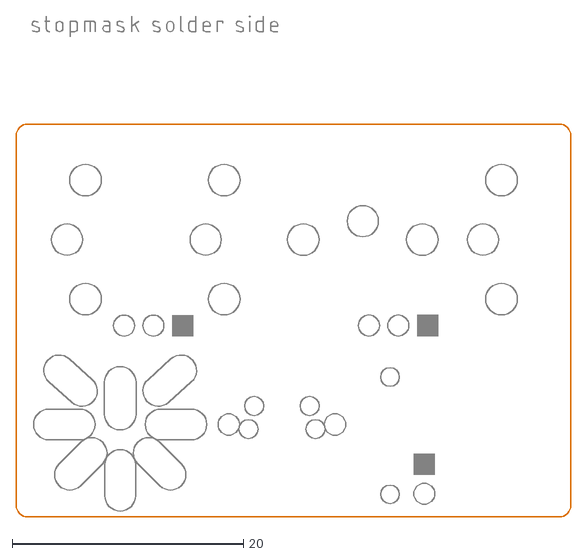
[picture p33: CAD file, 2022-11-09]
Rev. 1/dxf/C128_AV-Adapter_solderPads.dxf
48.0 x 43.3

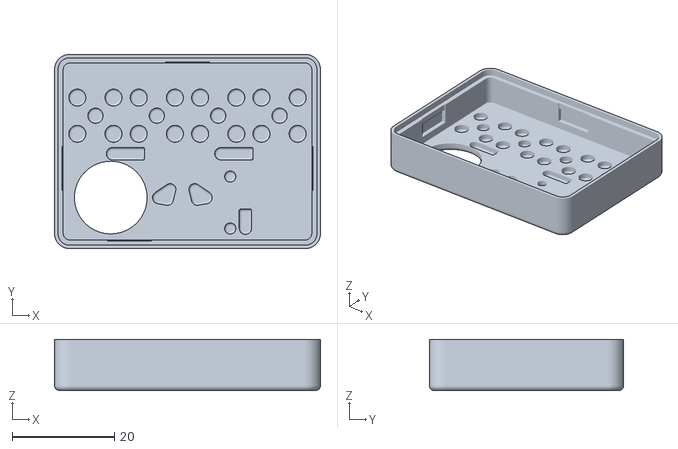
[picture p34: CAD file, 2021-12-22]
3D-printed case/Rev. 0/stl/C128_AVada_bottom.stl
52.0 x 38.0 x 10.0

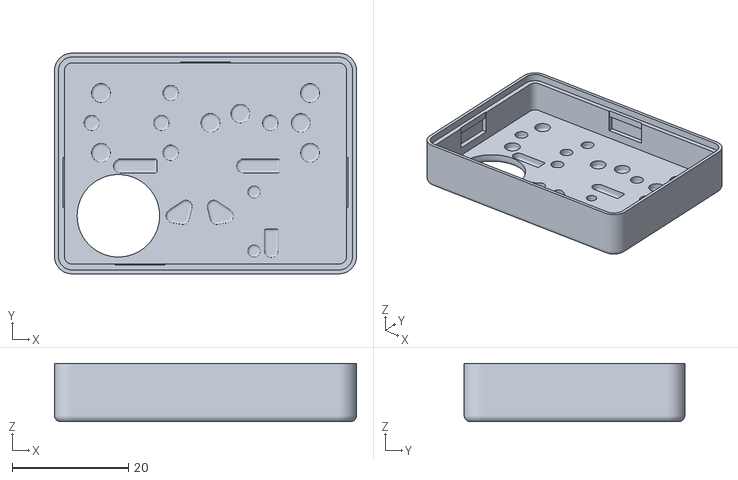
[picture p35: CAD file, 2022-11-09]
3D-printed case/Rev. 1/stl/C128AV_Bottom_v1.stl
52.0 x 38.0 x 10.0

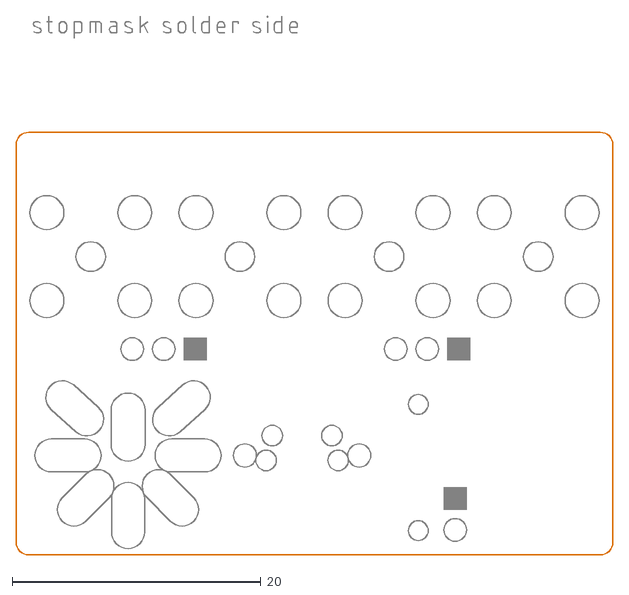
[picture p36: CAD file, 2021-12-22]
Rev. 0/dxf/C128_AV-Adapter_bstop.dxf
48.0 x 43.3

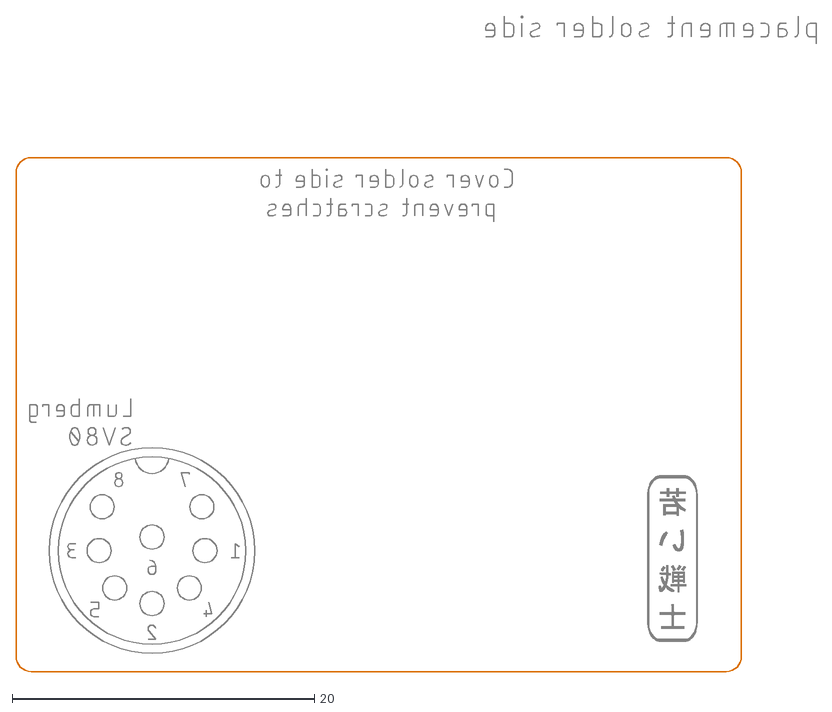
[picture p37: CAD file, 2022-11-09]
Rev. 1/dxf/C128_AV-Adapter_bottom.dxf
52.9 x 43.3

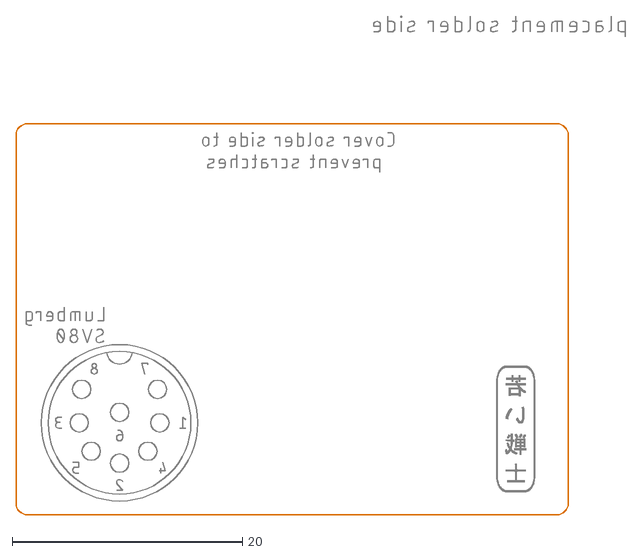
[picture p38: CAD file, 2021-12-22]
Rev. 0/dxf/C128_AV-Adapter_bot.dxf
52.9 x 43.3

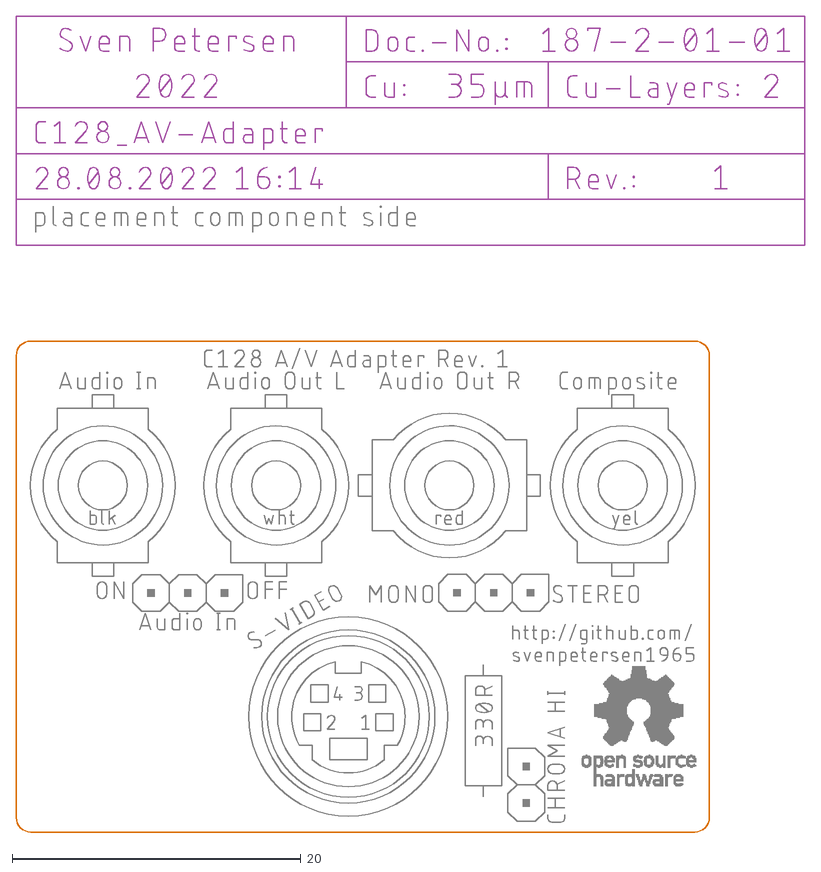
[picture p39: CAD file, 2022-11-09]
Rev. 1/dxf/C128_AV-Adapter_top.dxf
54.6 x 56.5

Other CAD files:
3D-printed case/Rev. 1/stl/C128AV_top_v1.stl
3D-printed case/Rev. 0/fusion360/C128_av_ada_v0 v12.f3d
3D-printed case/Rev. 1/Fusion360/C128_av_ada_v1 v2.f3d

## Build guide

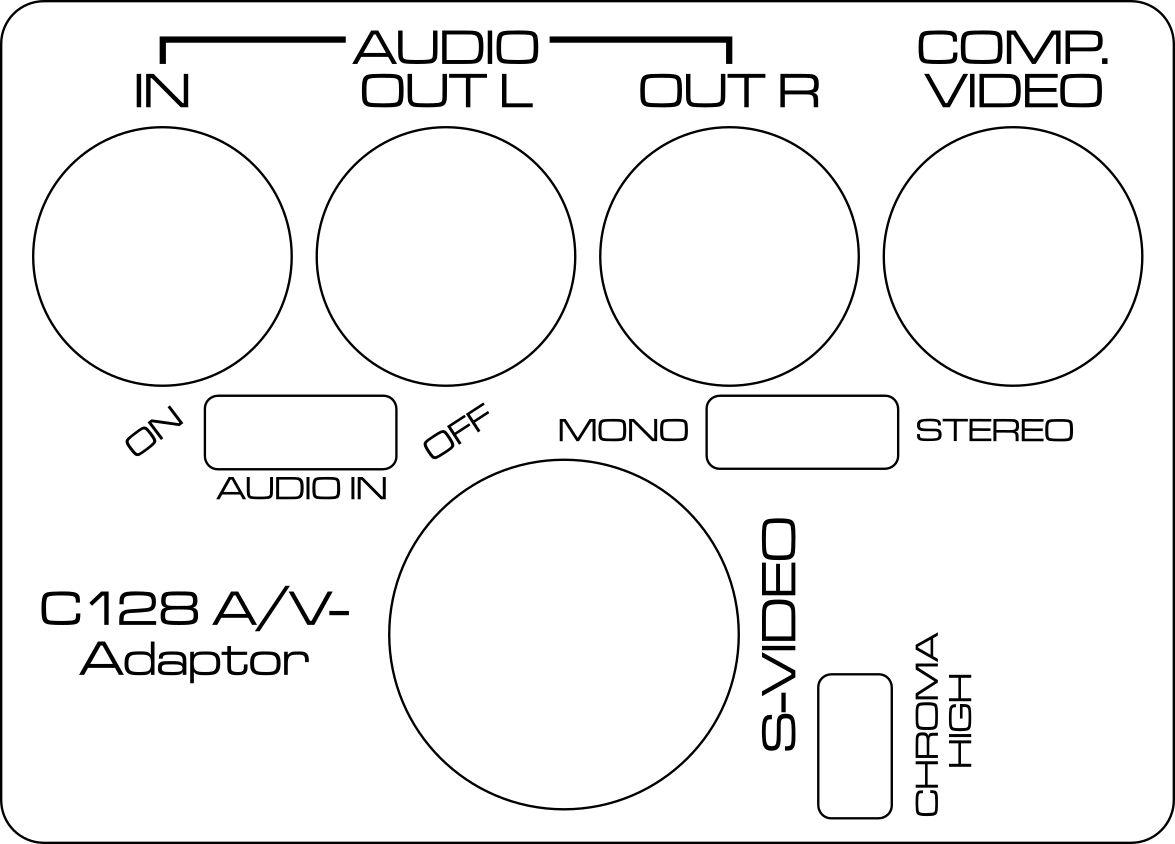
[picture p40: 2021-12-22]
3D-printed case/Rev. 1/Label/Label.png

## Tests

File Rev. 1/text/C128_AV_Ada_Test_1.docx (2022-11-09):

C128 A/V-Adaptor Rev. 1

Testing v1.0

# Introduction

The test was conducted with a prototype of the A/V-Adaptor Rev. 1. For the electrical/functional tests a C128 was used. A Framemeister XRGB mini was used to connect an (HDMI) monitor.

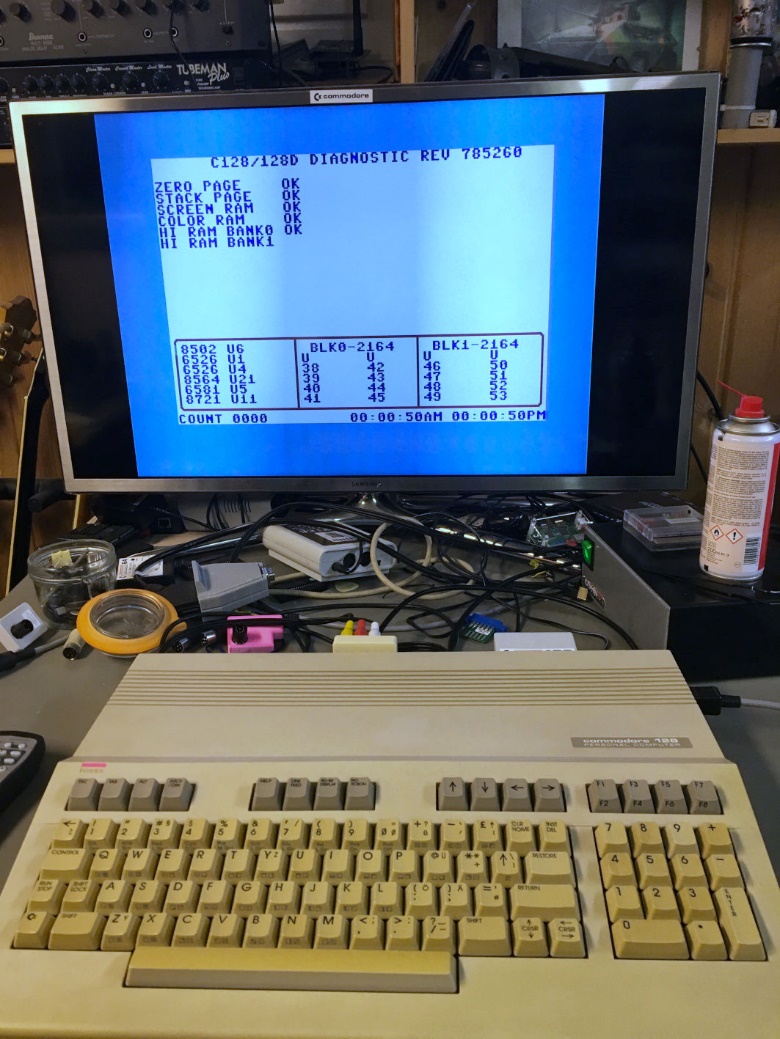
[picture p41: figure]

Figure 1: Test Setup

# Tests

## Assembly

The prototype was assembled, all footprints worked out. The DIN plug was assembled the way described in the Module Description. No problems occurred while the assembly.

## Mechanical fitting

The A/V-Adaptor was installed on a C128, which works well with the prototype. It is required to install the DIN plug with a distance to the bottom side of the PCB to get deep enough into the video jack of the C128 to obtain a stabile seating.

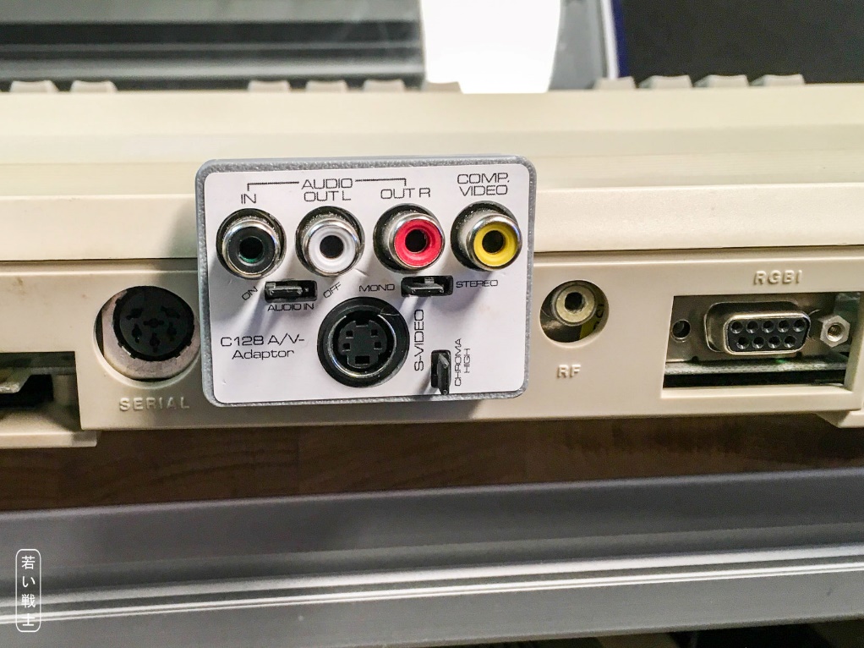
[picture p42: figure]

Figure 2: Mechanical testing with a C128.

No ports are blocked.

## Functional testing

The A/V-adaptor was connected to the C128 and the computer was switched on. The jumpers were set to

Jumper | Setting
JP1 (Chroma Hi) | Close (=330R resistor bridged)
JP2 (Audio in) | Off (audio in → GND)
JP3 (mono/stereo) | Mono (both audio channels connected to J2, Pin 3)

Test | Result | Testing
S-Video cable connected | The displayed image was clear and not distorted | Ok
Audio cable | Both speakers had a clear audio output (mono) | Ok
Composite video | The displayed image was clear and not distorted | Ok
Audio input (JP2 → on) | The audio signal connected was passed through the filter. | Ok
Stereo mode | TBD | TBD
Chroma high (s-video), 330R resistor bridged | The quality of the displayed imaged changed. The colors got stronger and slightly distorted. This was expected. | Ok

The stereo mode was not tested.

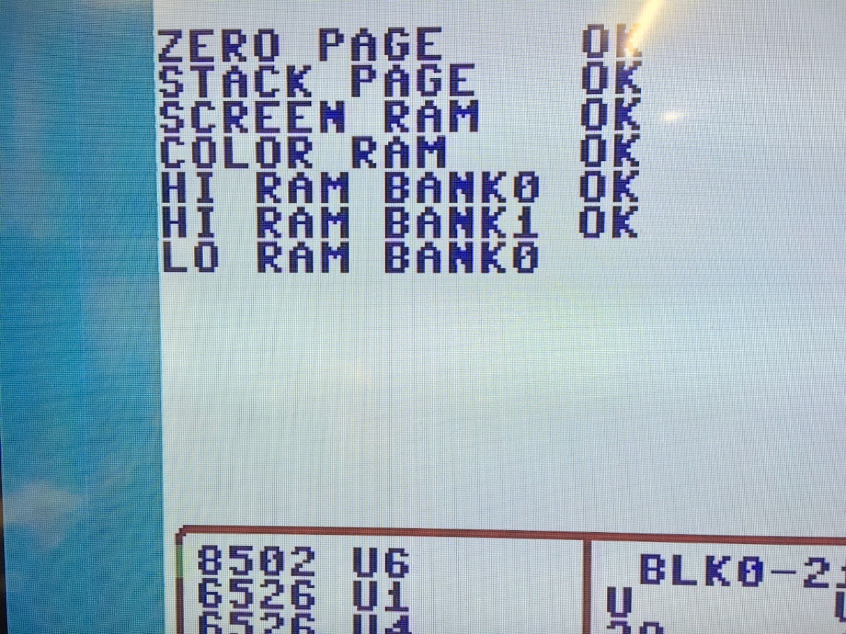
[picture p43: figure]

Figure 3: Photography of the S-Video output

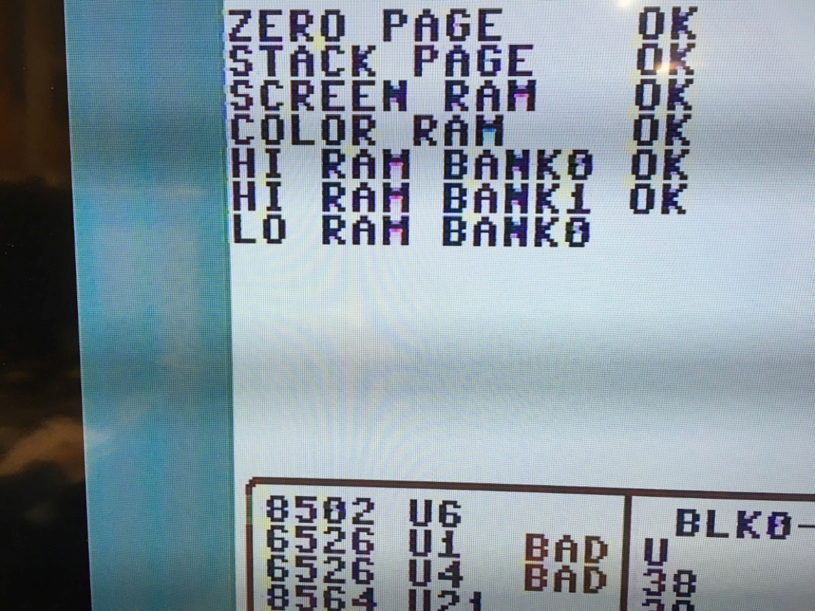
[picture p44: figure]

Figure 4: Photography of the Composite Video output

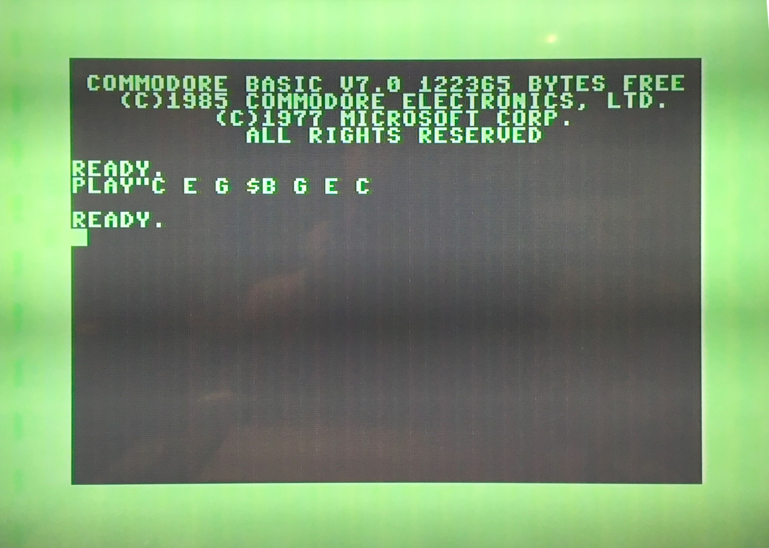
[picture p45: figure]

Figure 5: Sound test

The sound test was accomplished by playing some notes from BASIC V7.0. These were audible.

NOTE: Photographing an TFT/LCD-Display never really shows the real image. That is matter due to raster effects (Moiré patterns) and dynamic effects (darker areas/strips).

## 3D-printed cases

After trimming the solder pins of the RCA jacks, all three versions of the board fit into the bottom shell. The respective top shells could be installed and fit well. The decals (labels) fit on the top shell.

The A/V-Adaptors passed a drop test (a drop of 1m on a table top).

# Test Result

The C128 A/V-Adaptor Rev. 1 is fully functional. It seems, that the colors of s-video and composite video are looking more similar, when the jumper “Chroma High” is bridged.

C128_AV_Ada_Test_1.docx 09.11.2022 17:33 Drafted by Sven Petersen Page 2 of 2 Doc.-No.: 187-6-02-01

C128_AV_Ada_Test_1.docx 09.11.2022 17:33 Drafted by Sven Petersen Page 1 of 1 Doc.-No.: 187-6-02-01

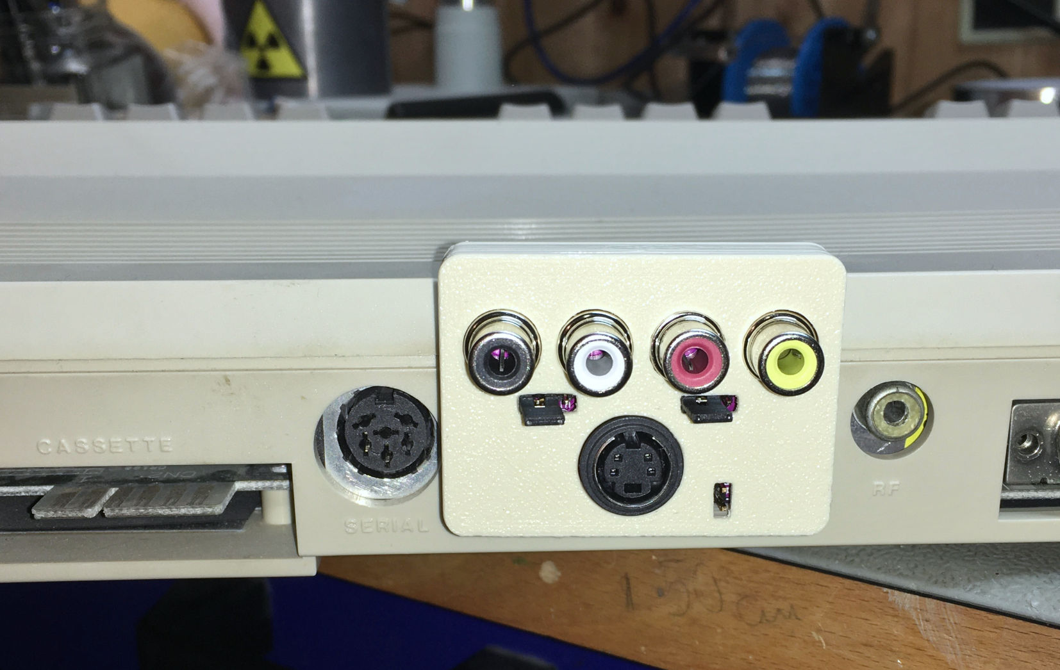
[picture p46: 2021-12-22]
Rev. 0/pictures/0478_-_mech_test.JPG

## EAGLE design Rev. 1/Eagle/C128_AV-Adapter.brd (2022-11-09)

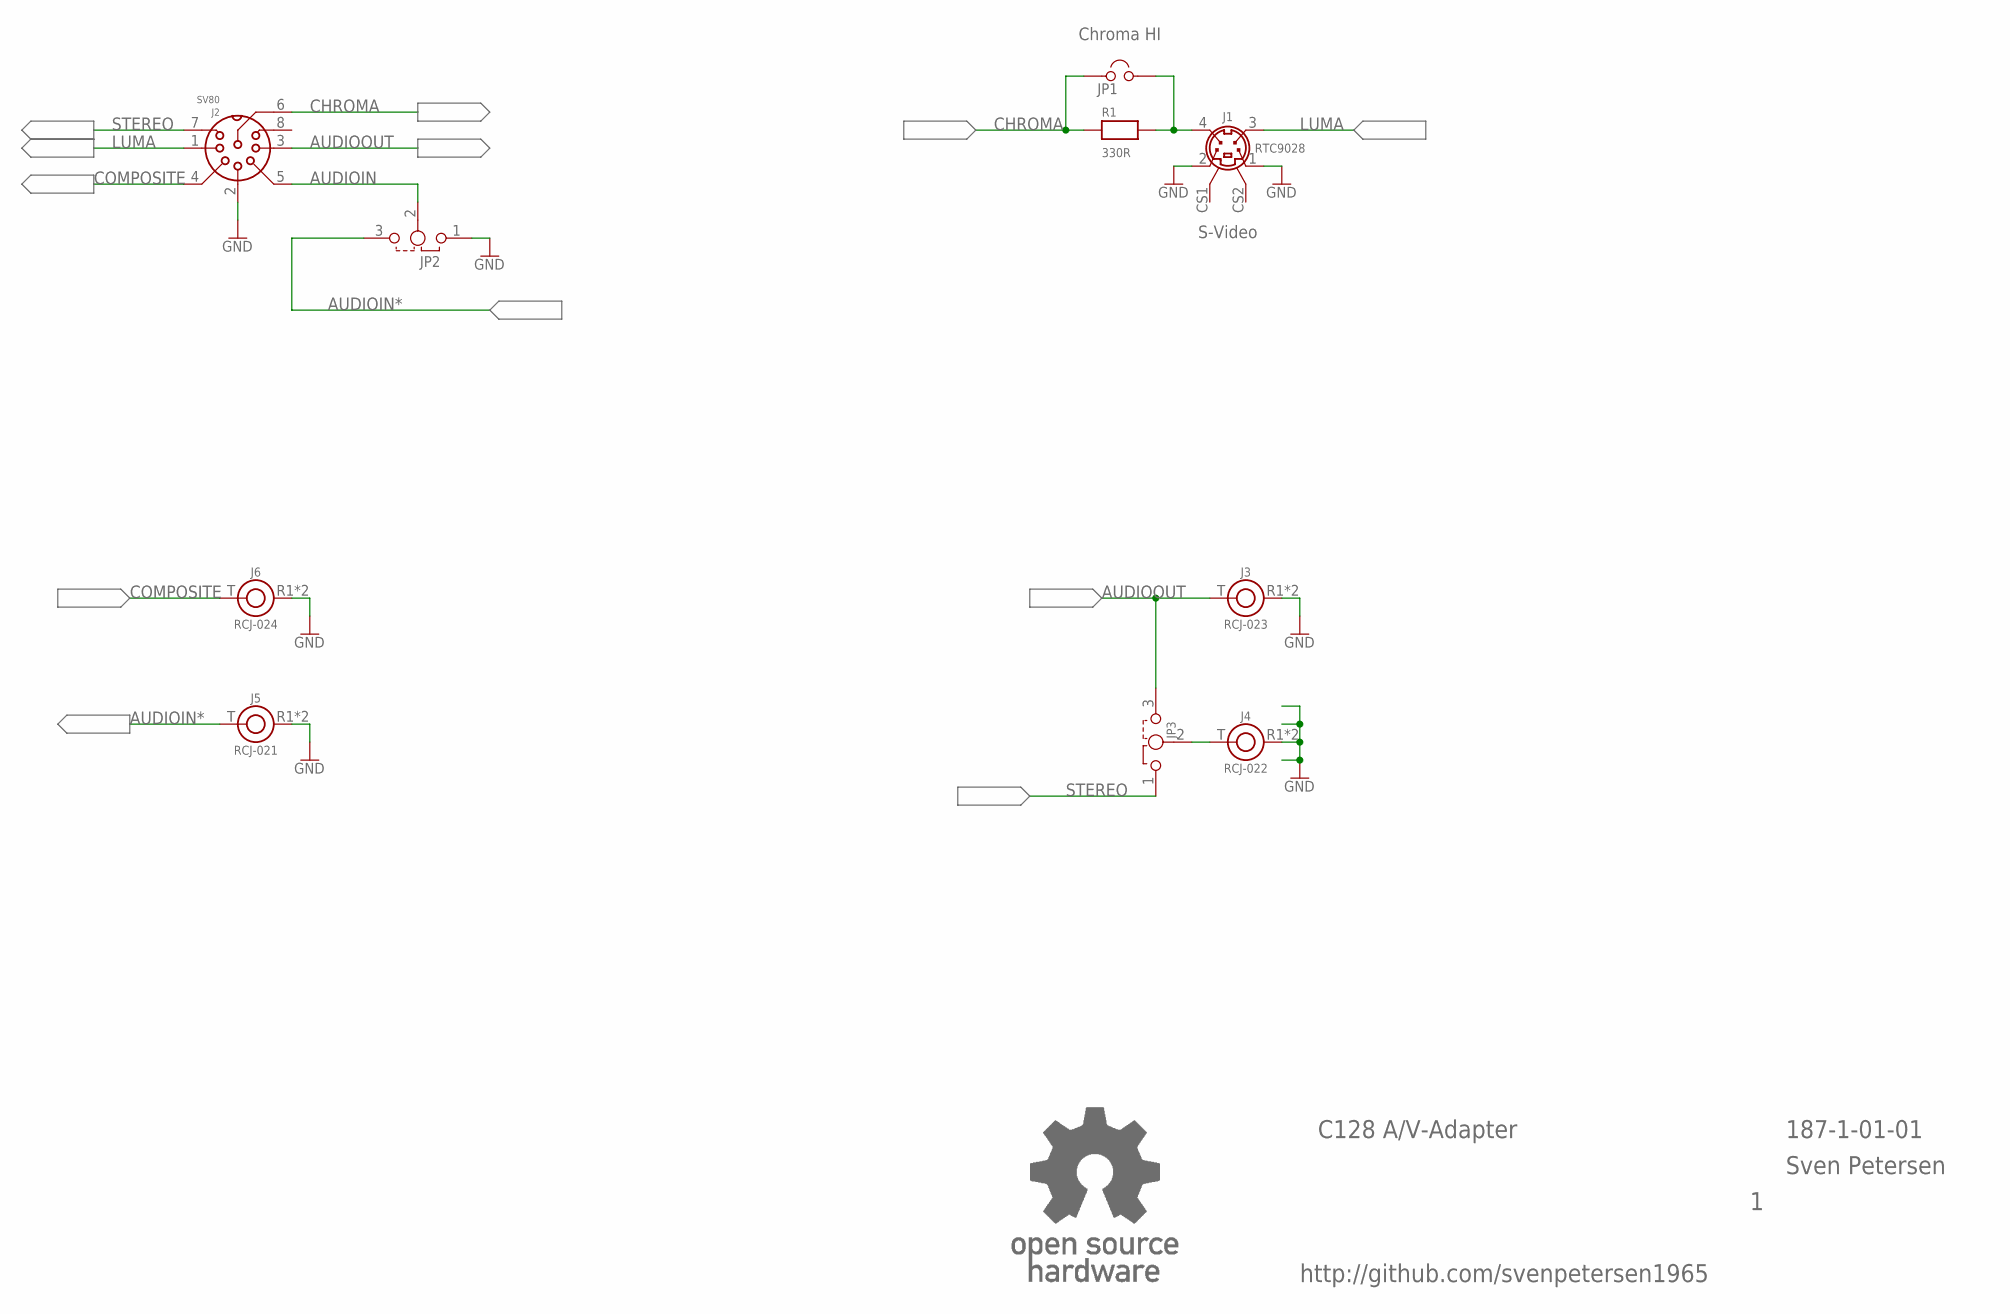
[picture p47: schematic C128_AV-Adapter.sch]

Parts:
J1: RTC9028; MINIDIN4_V
J2: SV80; SV80_INNER
J3: RCJ-023; RCJ-02X
J4: RCJ-022; RCJ-02X
J5: RCJ-021; RCJ-02X
J6: RCJ-024; RCJ-02X
JP1: JUMPER; 1X02
JP2, JP3: DJUMPER; 1X03
R1: 330R; R-10
U$25: OPEN_SOURCE_HW; OPENHW

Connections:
AUDIOIN: J2.5, JP2.2
AUDIOIN*: J5.T, JP2.3
AUDIOOUT: J2.3, J3.T, JP3.3
AUDIOR: J4.T, JP3.2
CHROMA: J2.6, JP1.1, R1.1
COMPOSITE: J2.4, J6.T
GND: J1.1, J1.2, J2.2, J3.R1 (R), J3.R2 (R), J4.R1 (R), J4.R2 (R), J5.R1 (R), J5.R2 (R), J6.R1 (R), J6.R2 (R), JP2.1
LUMA: J1.3, J2.1
unnamed: J1.4, JP1.2, R1.2
STEREO: J2.7, JP3.1

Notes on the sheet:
C128 A/V-Adapter
187-1-01-01
Sven Petersen
http://github.com/svenpetersen1965
Chroma HI
S-Video

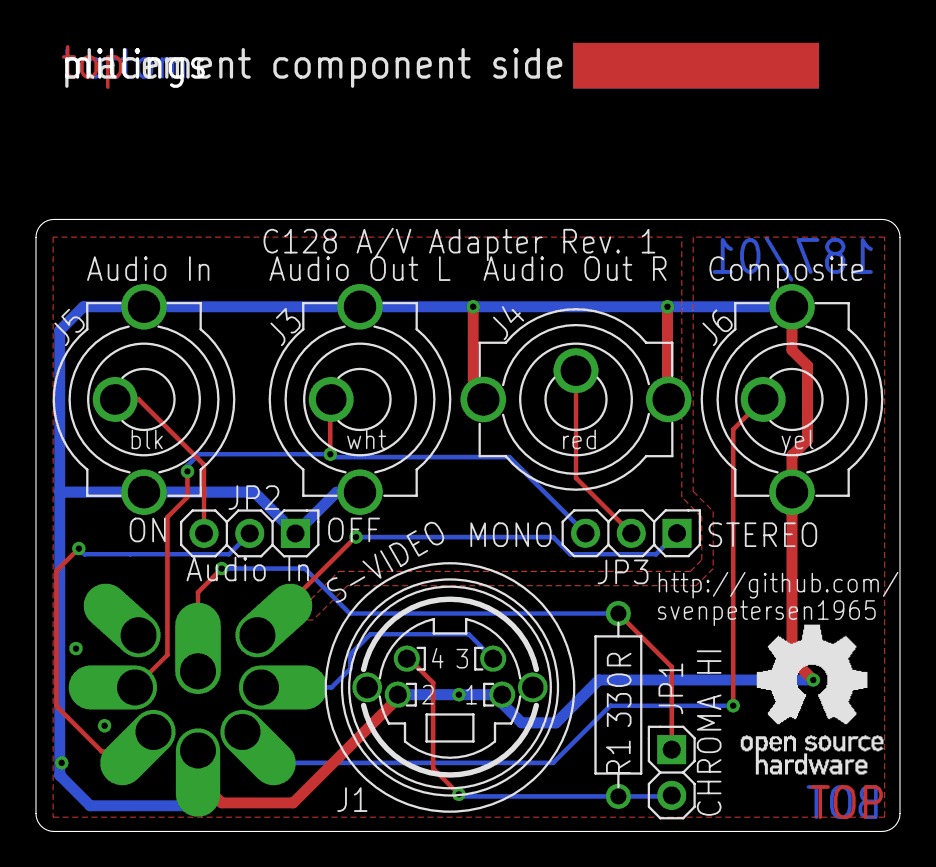
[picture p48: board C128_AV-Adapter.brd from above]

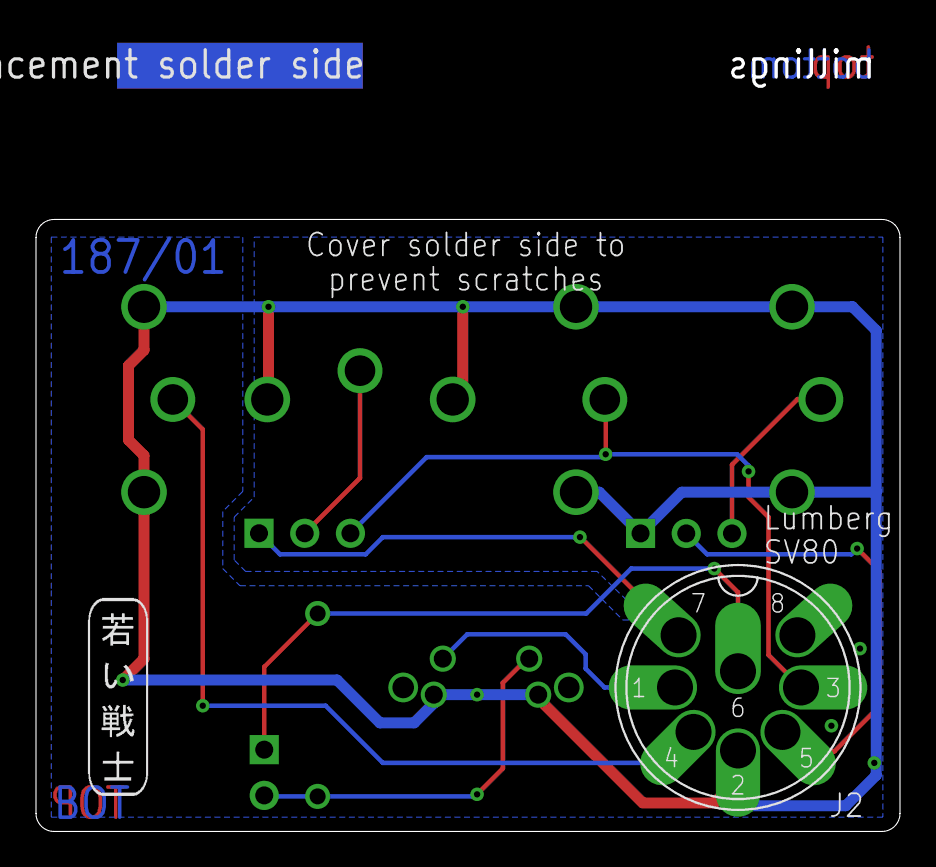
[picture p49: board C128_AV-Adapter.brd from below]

Board: 2 copper layers, 48.0 x 34.0 mm, 14 parts (2 on the bottom side), 10 nets.

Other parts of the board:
U$22: 2LAYER
U$23: SVEN_TAG
U$24: PCB-TITLE/

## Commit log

2021-12-22 Initial release
    [C128_AV-Adapter.brd, C128_AV-Adapter.sch, C128_AV-Adapter_bot.dxf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]
2022-02-26 Gerbers removed
2022-11-09 Rev. 1 released
    In Rev. 1, the obsolete Lumberg BTOR1 RCA jacks are replaced with CUI Inc. connectors.
    [C128_AV-Adapter.brd, C128_AV-Adapter.sch, C128_AV-Adapter_bottom.dxf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]
2022-11-09 Case Rev. 1 released
    The PCB Rev. 1 requires a different case. The label stays the same.
    [C128AV_Bottom_v1.stl, C128AV_top_v1.stl, C128_av_ada_v1 v2.f3d]
